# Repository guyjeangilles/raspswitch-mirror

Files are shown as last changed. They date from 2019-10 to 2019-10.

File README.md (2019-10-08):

----
# Table of Contents #
* [Introduction](#introduction)
* [Design Overview](#design-overview)
  * [Console](#console)
  * [DuinoCon](#duinocon)
* [Full Component List](#component_list)
* [Setting up the blueSMIRF as an HID Device](#setting_up_the_blueSMIRF)
* [Test The Gamepad Functionality](#test_the_gamepad)
* [Setting Up RetroPie](#setting_up_retropie)
* [Mechanical Assembly Sanity Check](#mechanical_assembly)
* [Full Assembly](#full_assembly)
  * [Console Assembly](#console_assembly)
  * [Gamepad Assembly](#gamepad_assembly)

----
**This repo is hosted on [Gitlab](https://gitlab.com/guyjeangilles/raspswitch.git). Any issues or pull requests on Github will be ignored and closed.**

# Introduction #
Welcome to the RaspSwitch repo. The steps in this readme instruct how to make
a Nintendo Switch-inspired handheld retro-gaming console. What makes this unique to other
variants is a DIY bluetooth, collapsible gamepad deemed the _DuinCon_.
 Heavy inspiration from the [SwitchBerry.](https://github.com/drew-wallace/switchberry)

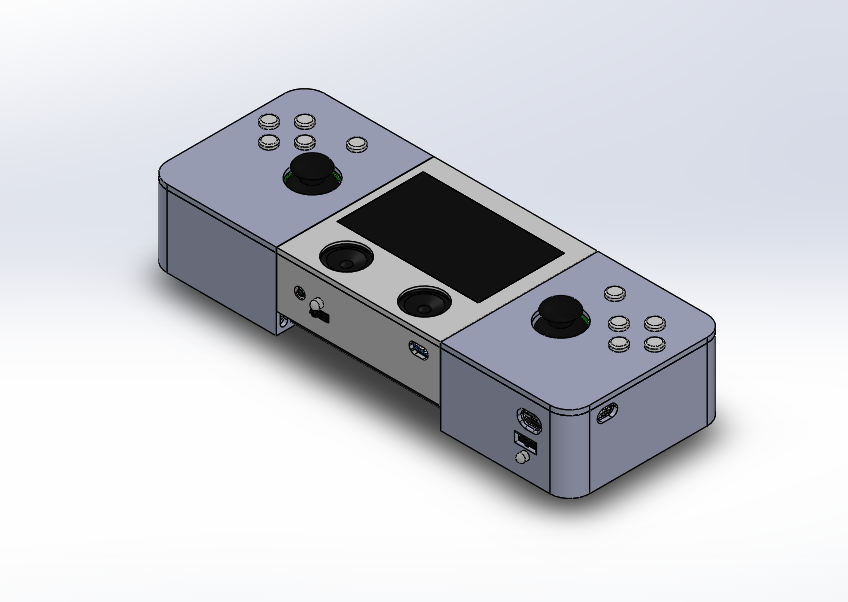
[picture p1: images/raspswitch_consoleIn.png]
RaspSwitch Console In CAD Render

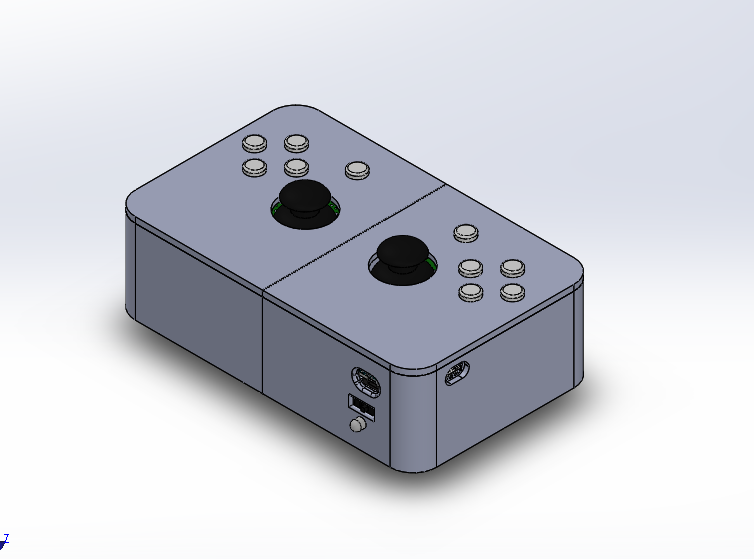
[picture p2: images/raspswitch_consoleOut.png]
RaspSwitch Console Out CAD Render


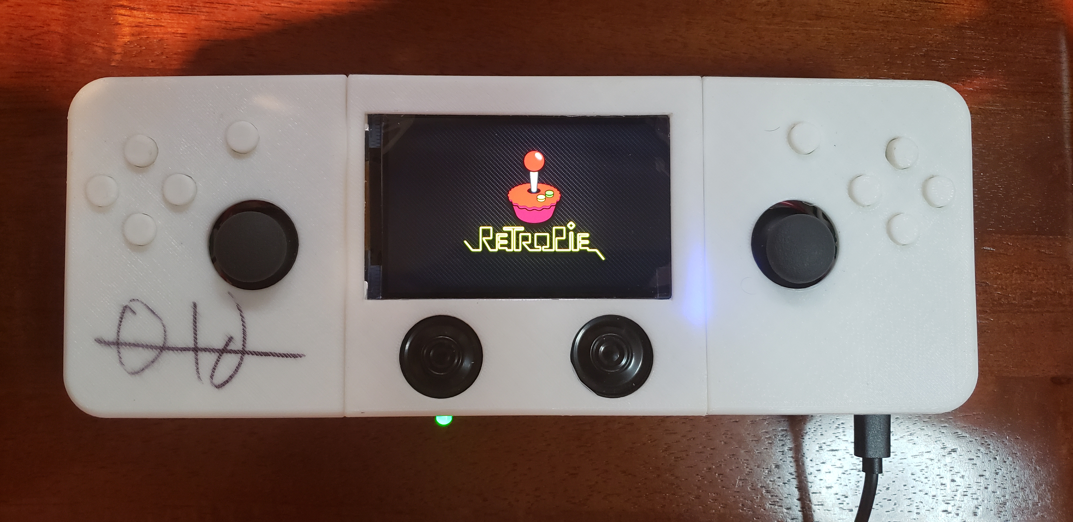
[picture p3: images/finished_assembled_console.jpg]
Finished Assembled Console

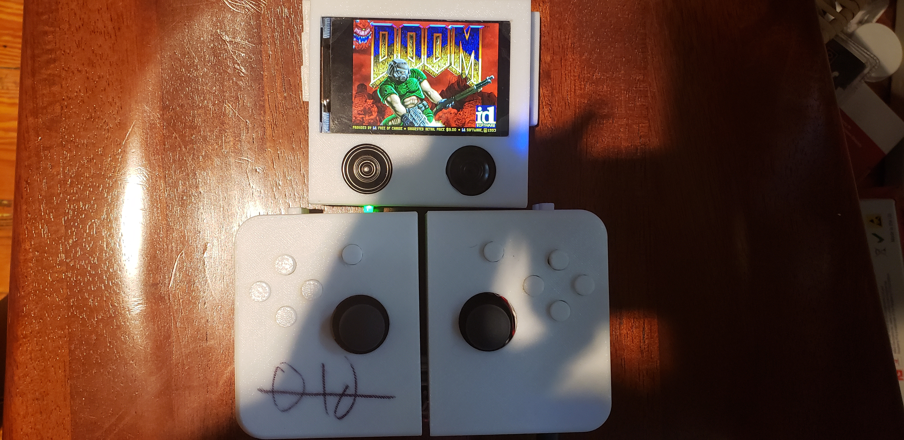
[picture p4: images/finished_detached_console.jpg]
Finished Detached Gamepad


# Design Overview #
Below are wiring diagrams of the RaspSwitch. These are for **reference only**.
Make sure you understand each component's function.

## Console ##

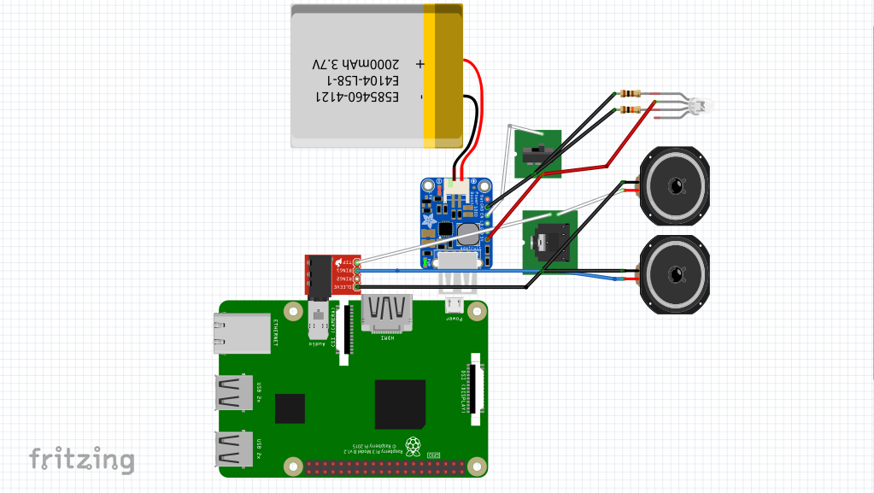
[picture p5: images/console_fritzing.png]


The console consists of a Raspberry Pi 3 A+ and the HyperPixel 4.0 as the display. A Powerboost 1000c and a 2500mAh lithium battery supply power. In practice, the battery life is ~1.5 hours. You can use an external battery pack to lengthen that. There's also circuitry to turn the console on and off with a switch, a power LED that turns on when the battery is low, and electronics that switch audio from the built-in speakers to headphones if they're plugged in.

_NOTE: I want to reiterate that the above is just for reference. Several elements are not in the fritzing diagram including the HyperPixel 4.0, USB cable from the PowerBoost 1000c, etc._

## DuinoCon ##

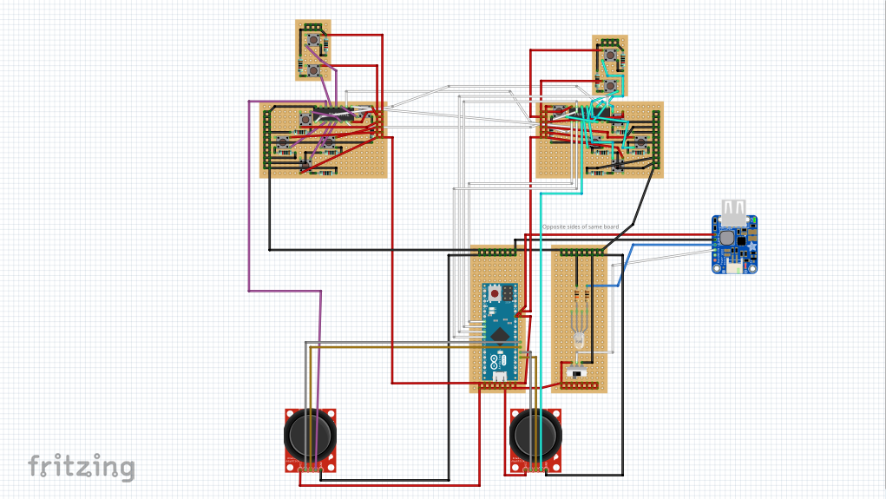
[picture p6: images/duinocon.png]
DuinoCon Fritzing Diagram


The bluetooth gamepad is fairly simple. It's main components are an Arduino Micro, two shift registers, two thumb joysticks, and a blueSMIRF module. A 1200mAh lithium ion battery and Powerboost 1000c supply power. I was getting 4+ hours of use from this battery. Mechanically speaking, the gamepad is one unit that can collapse instead of two separate gamepads like the Nintendo Switches joycons. I'll be honest, separate gamepads are probably more functional than a collapsible gamepad, but at least now you can learn from my mistakes.

# Full Component List #
- [Raspberry Pi A+ (USD 25.00 Oct2019)](https://www.adafruit.com/product/4027)
- [Arduino Micro (USD 19.80 Oct2019)](https://store.arduino.cc/usa/arduino-micro)
- [Hyperpixel 4.0 display (£36.50 Oct2019)](https://shop.pimoroni.com/products/hyperpixel-4)
- [blueSMIRF Silver (USD 27.95 Oct2019)](https://www.sparkfun.com/products/12577)
- [6" USB cable (USD 2.95 Oct 2019)](https://www.adafruit.com/product/898)
- [SN74HC165N shift register (USD 0.48 Oct2019)](https://www.digikey.com/product-detail/en/texas-instruments/SN74HC165N/296-8251-5-ND/376966)
- [M2 threaded inserts (USD 13.20)](https://www.mcmaster.com/94180a312)
- [M2x6 fasteners (USD 12.05 Oct2019)](https://www.mcmaster.com/91290a013)
- [M2x3 fasteners (USD 8.74)](https://www.mcmaster.com/91292a003)
- [M2 hex nuts (USD 4.11)](https://www.mcmaster.com/90695a025)
- [M2 washers (USD 1.06)](https://www.mcmaster.com/93475a195)
- [3" linear shaft (USD 4.56)](https://www.mcmaster.com/6061k411)
- [5" linear shaft (USD 5.07)](https://www.mcmaster.com/6061k413)
- [0.938" spring (USD 5.24)](https://www.mcmaster.com/9657k810)
- [0.5" spring (USD 7.87)](https://www.mcmaster.com/9657k268)
- [2500mAh Lithium ion battery (USD 14.95 Oct2019)](https://www.adafruit.com/product/328)
- [1200mAh Lithium ion battery (USD 9.95 Oct2019)](https://www.adafruit.com/product/258)
- [Powerboost 1000c(USD 19.95 Oct2019)](https://www.adafruit.com/product/2465)
- [Protoboards (USD 8.99 Oct2019)](https://www.amazon.com/Teenitor-Prototype-Project-Quality-Universal/dp/B01IONQQ3Y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)
- [3.5 mm audio plug (USD 2.50 Oct2019)](https://www.adafruit.com/product/2914)
- [3.5 mm audio jack (USD 0.95 Oct2019)](https://www.adafruit.com/product/1699)
- [Right angle HDMI adapter (USD 7.99 Oct2019)](https://www.amazon.com/DIZA100-4-Pack-Connectors-2-Pack-Adapters/dp/B01GFP4NQA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)
- [RGB led (USD 2.00 Oct2019)](https://www.adafruit.com/product/159)
- [SPDT switch (USD 0.95 Oct2019)](https://www.adafruit.com/product/805) _this is a little smaller than what the 3D printed parts call for but will still work_
- [Soft tactile momentary switch (USD 1.95 Oct2019)](https://www.adafruit.com/product/3101)
- [0.5W 1" speaker (USD 1.95 Oct2019)](https://www.adafruit.com/product/1890)
- [10k ohm resistors (USD 0.75 Oct2019)](https://www.adafruit.com/product/2784)
- [100 ohm resistor (USD 0.75 Oct2019)](https://www.adafruit.com/product/4293)
- [DIP IC sockets (USD 10.84 Oct2019)](https://www.amazon.com/Glarks-122Pcs-Sockets-Adaptor-Assortment/dp/B01GOLSUAU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)
- [Thumb joystick USD 3.95 Oct2019](https://www.sparkfun.com/products/9032)
- [Thumb stick breakout board (USD 1.95 Oct2019)](https://www.sparkfun.com/products/9110)
- Access to a 3D printer

# Setting up the blueSMIRF as an HID Device #
0. Load the Arduino Micro with command mode test firmware.
1. Send `$$$<cr>` via the serial monitor to enter command mode.
2. Send `SU,96` to change the baud rate to 9600 bps.
3. Send `S~,6` to switch the module to the HID profile.
4. Send `R,1` to reboot.
5. Send `SH,0220` to make the module a gamepad.
6. Send `GH` to check that it changed. The response needs to be `SA,1` or at least not `SA,0` to work.

# Test the gamepad functionality #
0. Follow the instructions in the firmware comments to wire the components on a breadboard.
Use the wiring diagrams and schematic as reference only. **DO NOT SOLDER ANYTHING YET.**
1. Connect to any bluetooth capable device and ensure the blueSMIRF is seen as a bluetooth joystick and all the buttons and analog axes work. I used [jstest-gtk](https://jstest-gtk.gitlab.io/) for debugging. There's probably a similar program for your OS.

# Setting up RetroPie #
0. Ensure you have a USB keyboard and a Ethernet connection.
1. Download RetroPie image.
2. Use [Etcher](https://www.balena.io/etcher/) (our your favorite image burning tool) to install RetroPie on a micro SD card.
3. Boot RetroPie on the Raspberry Pi.
4. Configure a USB keyboard as a RetroPie controller.
5. Update RetroPie.
6. Change the timezone to yours.
7. Change the keyboard layout to one you're familiar with.
8. Connect to wifi.
9. Enable autologin.
10. Enable SSH and change the password.
11. Register the DuinoCon as a bluetooth gamepad.
12. Configure DuinoCon as a RetroPie controller.
13. Force reconnection in background.
14. Install the HyperPixel 4.0 software with `curl https://get.pimoroni.com/hyperpixel4 | bash`
more info at https://learn.pimoroni.com/tutorial/sandyj/getting-started-with-hyperpixel-4

_NOTE: I've tried to configure the Raspberry Pi to switch between HDMI and the HyperPixel but have had modest success. You can read  up on it here and take your best shot https://forums.pimoroni.com/t/hyperpixel-selective-output-eg-on-boot/5193/3 ._

# Mechanical Assembly Sanity Check #
0. 3D print all the parts.

1. Before you install the threaded inserts,  you should assemble the 3D printed parts to make sure they mate as intended. You'll likely have to do some post-processing depending on the 3D printer you use. I modeled the parts to have excess material so they could be printed on any printer and be post-processed for proper assembly. Use the following steps as a minimum checklist for part assembly.

2. A micro SD card should be able to **slip** through slot on the side of the console. It should not stick...like at all.

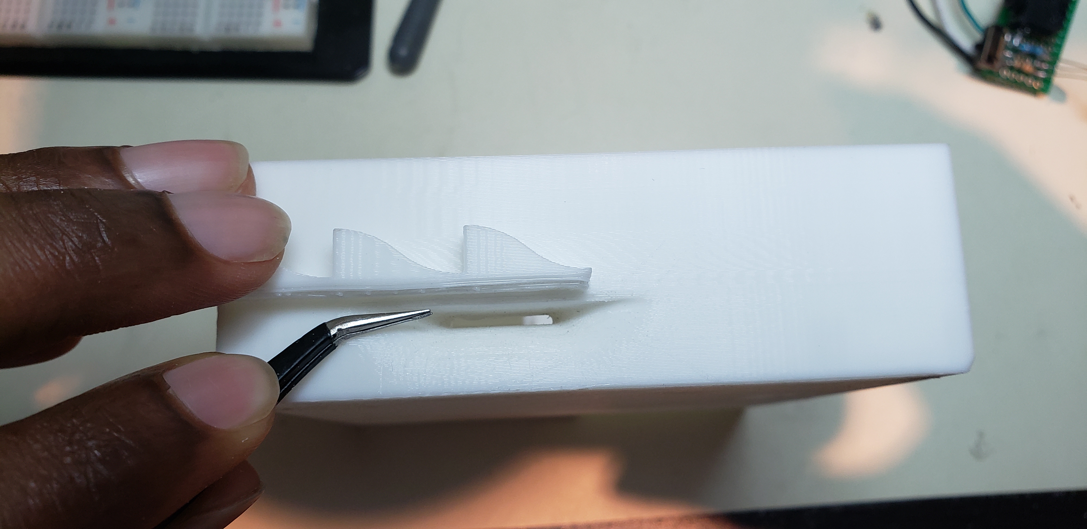
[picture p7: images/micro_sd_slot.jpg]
Micro SD Slot


3. The port for the headphone jack, SPDT switch, and RGB led  should **slip** into it's hole in the front of the console enclosure. A little sticktion is ok.

4. The console's tabs should **slip** into the gamepads slots. There should be **zero** stick...like at all.

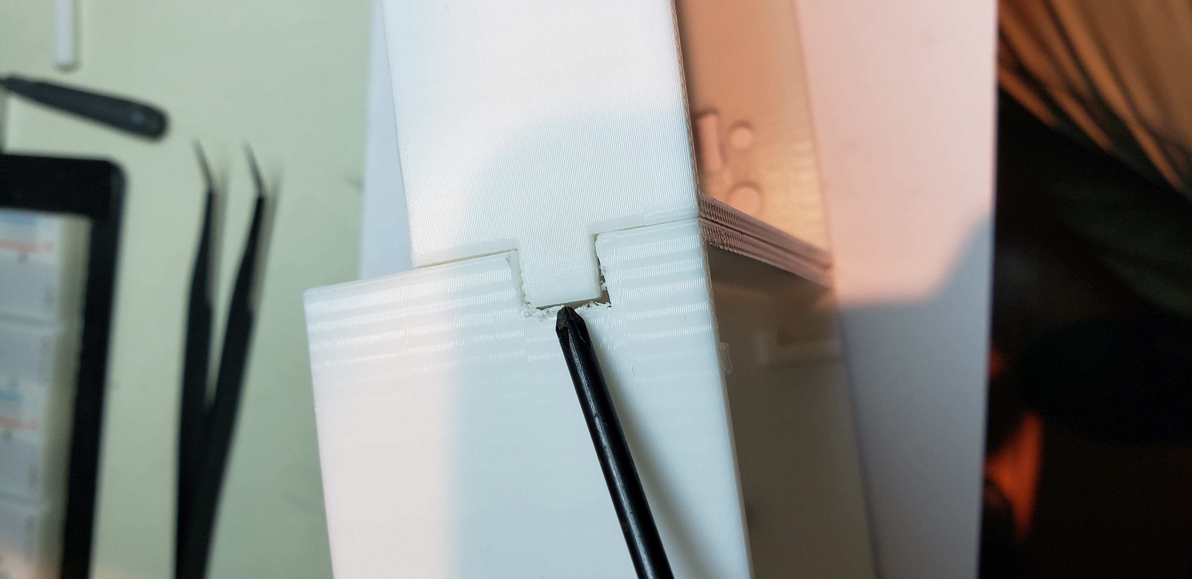
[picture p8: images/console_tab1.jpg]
Console Tabs

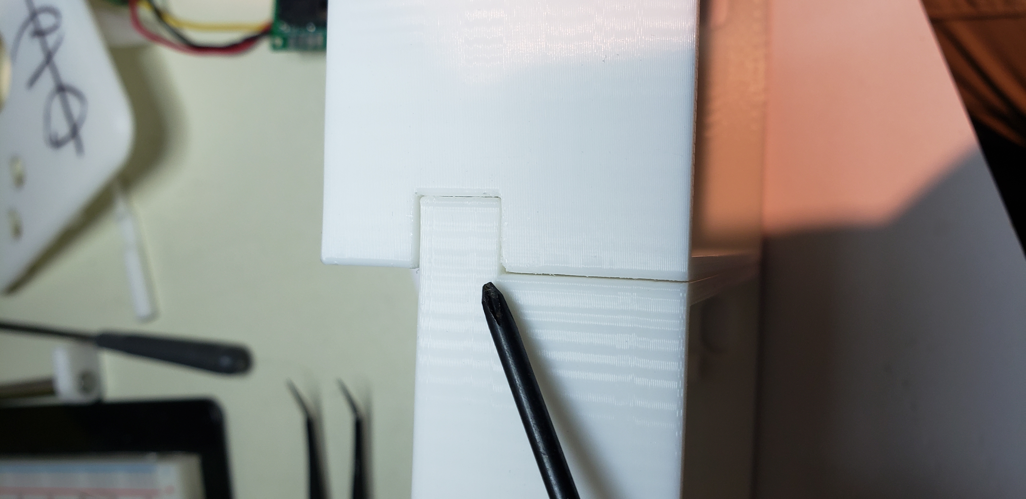
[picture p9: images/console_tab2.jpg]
Console Tabs


5. The slide bay should **slip** into the two halves of the gamepads. There should be **zero** stick...like at all.

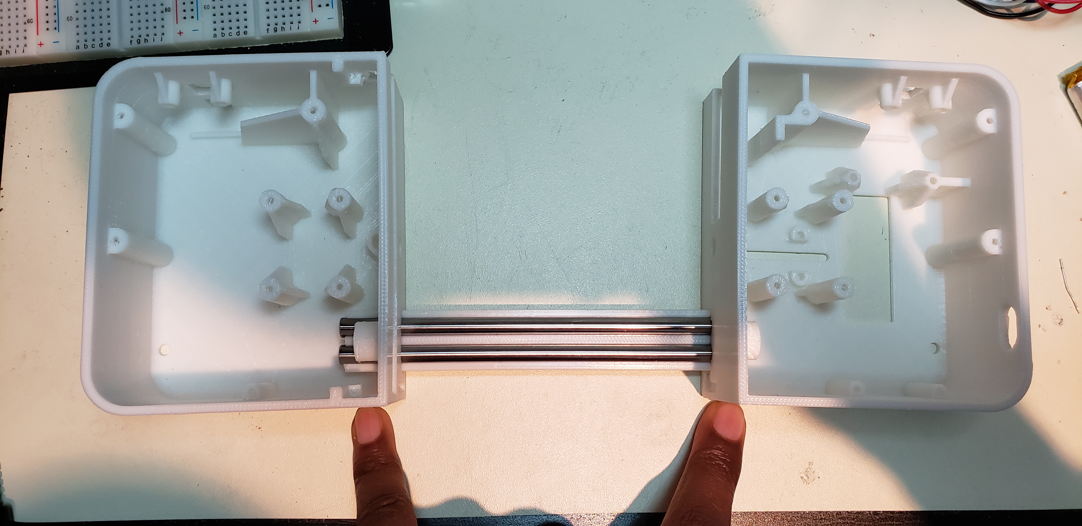
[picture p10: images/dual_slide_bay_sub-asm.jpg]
Dual Slide Bay in Gamepad Bottoms


6. The linear shaft should **slip** into the shaft guide. A little sticktion is ok.

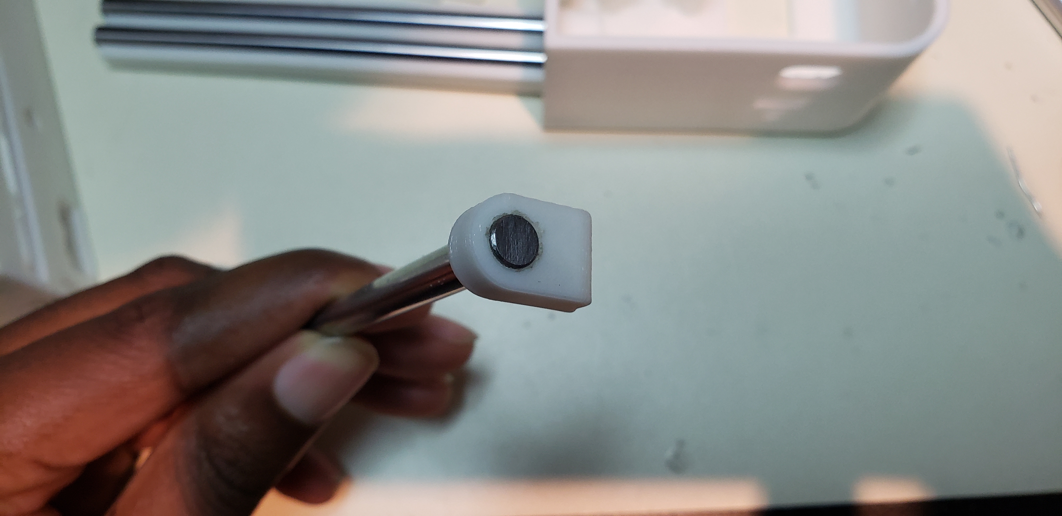
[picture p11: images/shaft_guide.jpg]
Shaft Guide


7. The console release tip should **slip** through it's housing in left gamepad half. There should be **zero** stick...like at all.

8. The console catch should **slip** though it's housing in the left gamepad half. There should be **zero** stick...like at all.

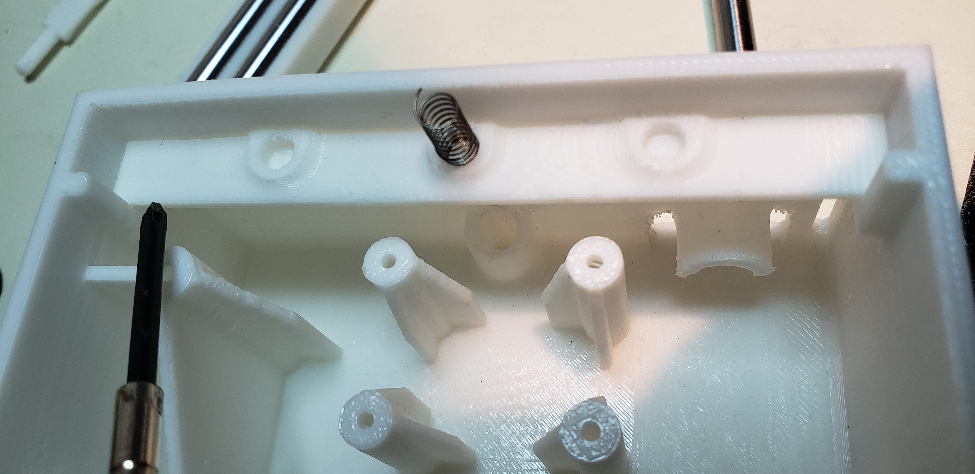
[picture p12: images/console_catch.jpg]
Console Catch


9. A spring should rest in the right gamepad catch enclosure when it's flipped upside down.

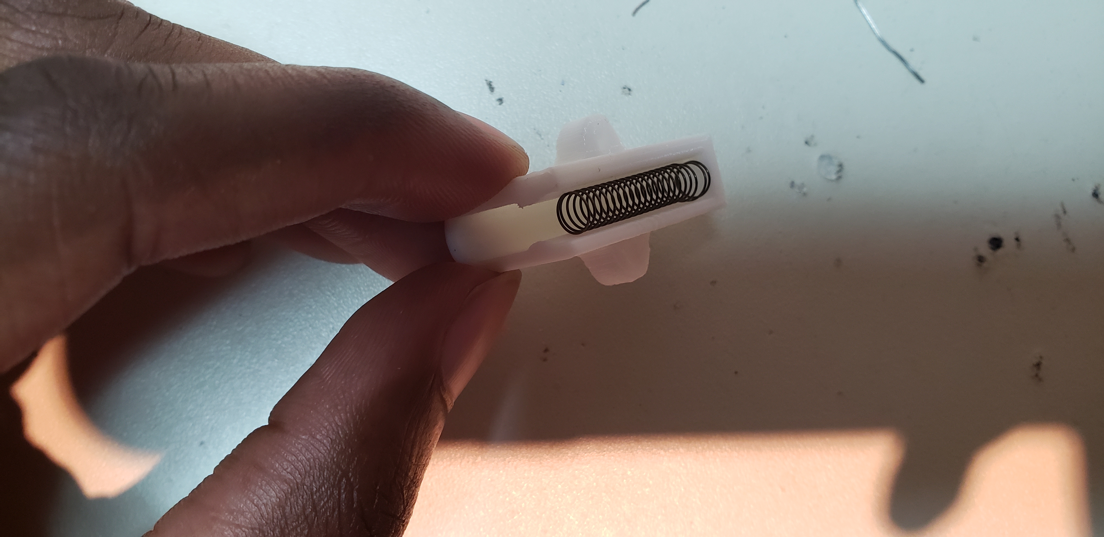
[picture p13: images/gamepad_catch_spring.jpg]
Gamepad Catch Spring


10. The assembled right gamepad catch should **slip** in and out of it's enclosure. There should be **zero** stick...like at all.

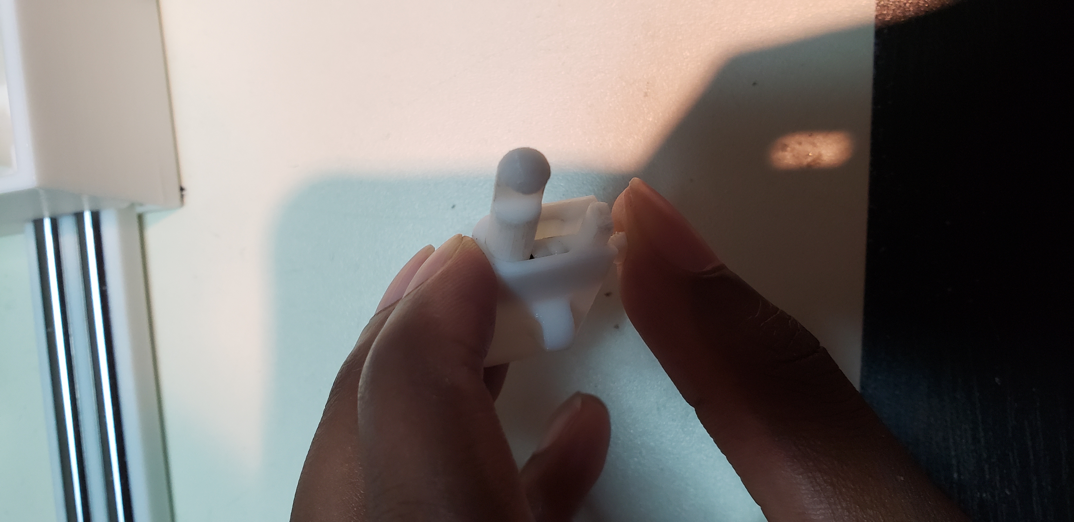
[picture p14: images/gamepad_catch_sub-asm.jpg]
Gamepad Catch Subassembly


# Full Assembly #

_NOTE:_ I'd recommend only charging one battery and leaving another in a low/near-dead state to troubleshoot the low battery fuction of the 1000C.

_ANOTHER NOTE:_ I'd recommend using stranded wire as it's more flexible than solid core.

_ONE MORE NOTE:_ You will need to cut the protoboards I link to in the full component list. I did this easily with a dremel tool.

## Console Assembly ##

### Console Component list ###

- Raspberry Pi A+ x1
- Hyperpixel 4.0 display x1
- GPIO header extension x1
- M2.5 mm shoulder x4
- M2.5 fasteners x4
- M2 threaded inserts x12
- M2x6 fasteners x10
- M2x3 fasteners x2
- 2500mAh Lithium ion battery x1
- Powerboost 1000c x1
- Appropriately sized protoboard for audio/power circuit x1
- 3.5 mm audio jack x1
- 3.5 mm audio plug x1
- Right angle HDMI adapter x1
- RGB led x1
- SPDT switch x1
- 0.5W 1" speaker x2
- 10k ohm resistor x1
- 10 ohm resistor x1
- all 3D printed parts

0. Test your components on a breadboard

1. Seriously, save yourself some time and connect everything, raspberry pi, Arduino, all the components on a breadboard and use the joysticks, buttons, headphone jacks, switches...test all of this before you start soldering anything.

2. Make sure you did the mechanical assembly right.

3. I'm being repetitive but seriously if you skipped the mechanical assembly part above go back up and do it.

4. Solder the audio/power PCB including the Powerboost 1000c, 3.5mm plug, and speakers that I forgot to solder in the photo below.

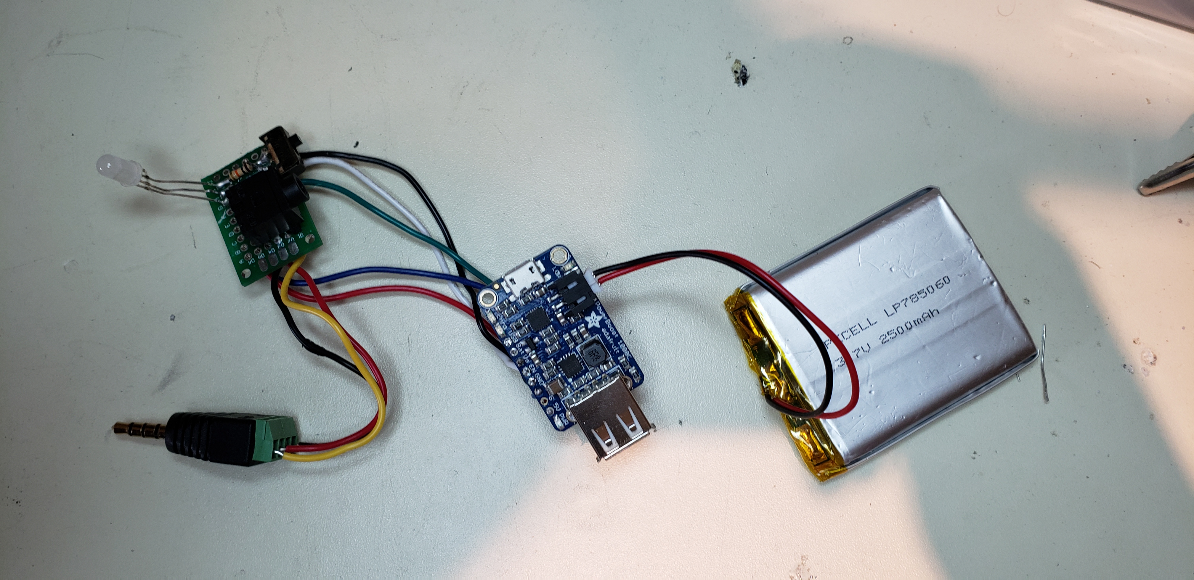
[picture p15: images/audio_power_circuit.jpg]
Audio/Power Circuit


5. Test that the audio jack and speakers work in a known good audio source. Also, check that the LED turns green and red as expected and the slide switch works.

6. Install the threaded inserts in the top and bottom half of the console enclosures.

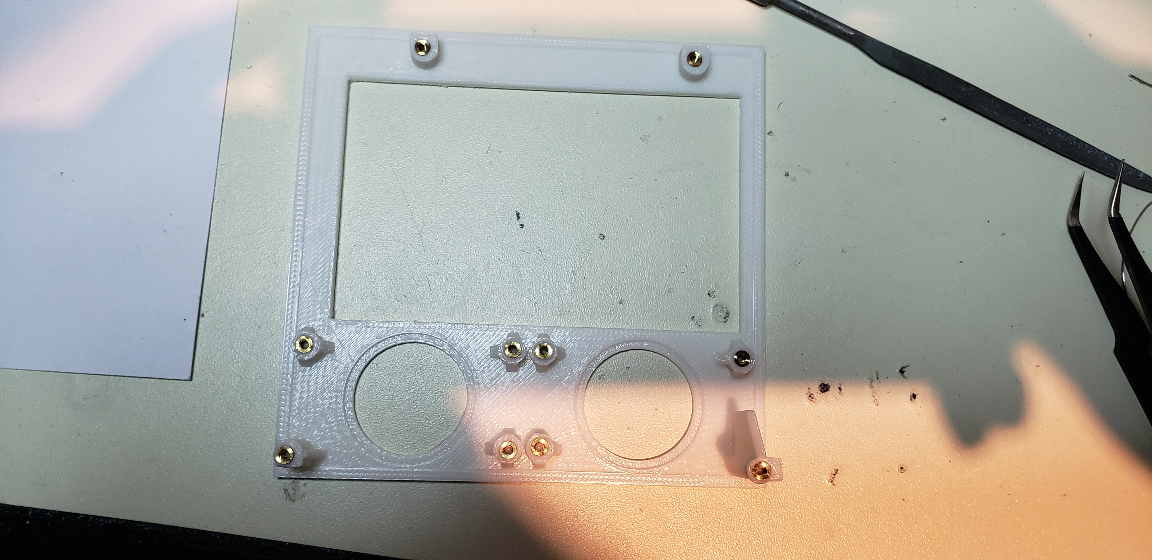
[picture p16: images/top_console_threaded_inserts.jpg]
Top Console Threaded Inserts


7. Install the audio/power PCB, don't install the Powerboost 1000c yet. The M2X3 fastener works best here.

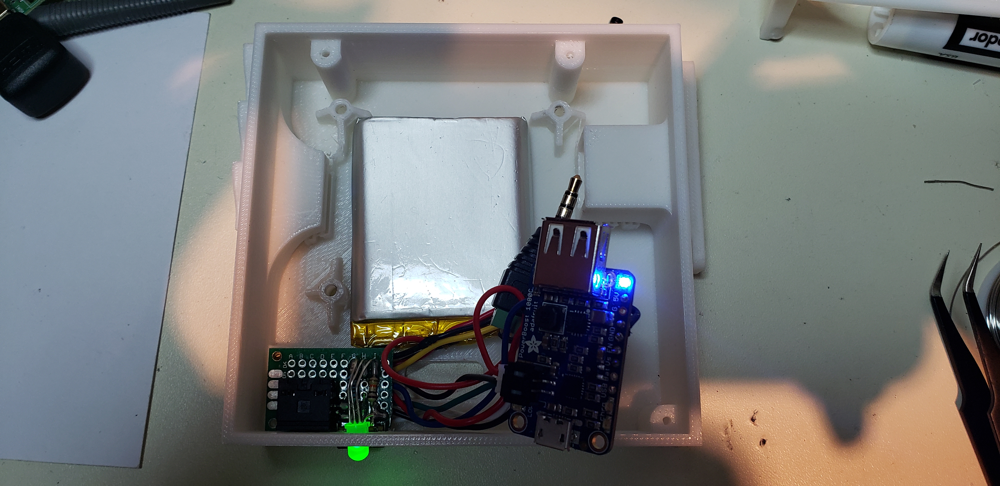
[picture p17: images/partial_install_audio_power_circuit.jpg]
Partial Install of Audio/Power Circuit


8. Install the HDMI adapter and3.5mm plug onto the Pi. Then install the Pi into the bottom half of the console enclosure **without** the micro SD card.  It's easiest to slide the Pi in sideways.

9. Install the Powerboost 1000c, but don't fasten down the fastener too tight as you might need to adjust it for the next step. The M2x3 fastener works best here.

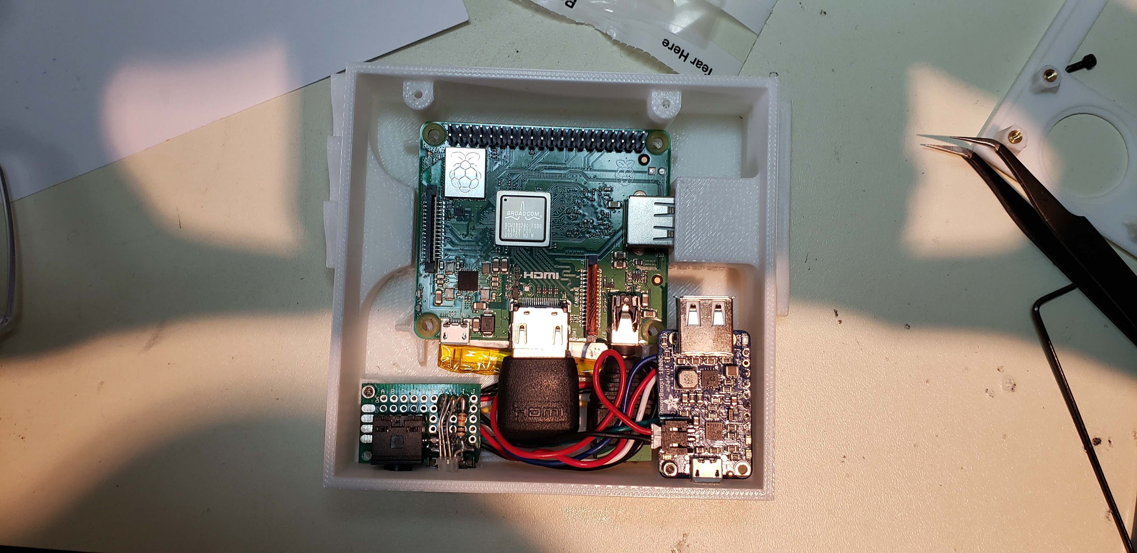
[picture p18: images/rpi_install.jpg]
Raspberry Pi Installed


10. Attach a USB cable to the Powerboost 1000c and Raspberry Pi. You might need to push down the LED wires to accomplish this.

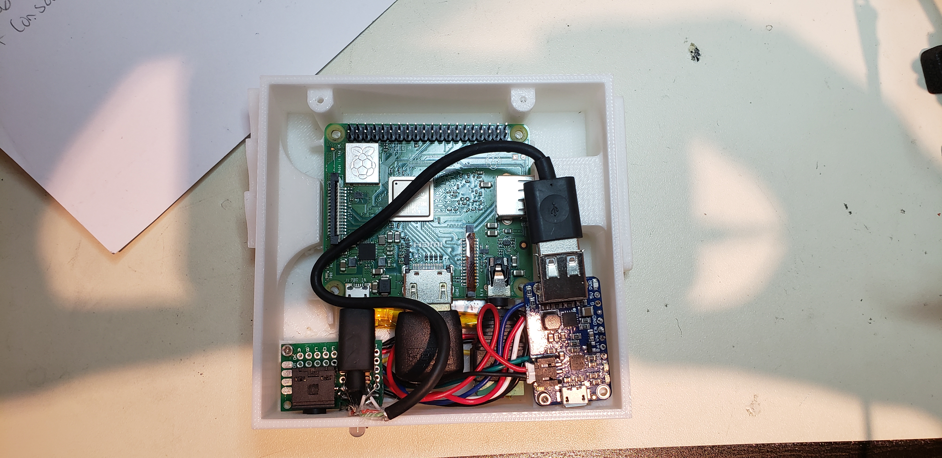
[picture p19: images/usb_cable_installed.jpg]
USB Cable Installed


11. Install the threaded inserts and header pin extender onto the Hyperpixel 4.0. Then install the Hyperpixel 4.0 onto the Raspberry Pi. Once the screen is on, screw in the fasteners included with the display (M2.5) from the bottom half of the console into the raspberry pi.

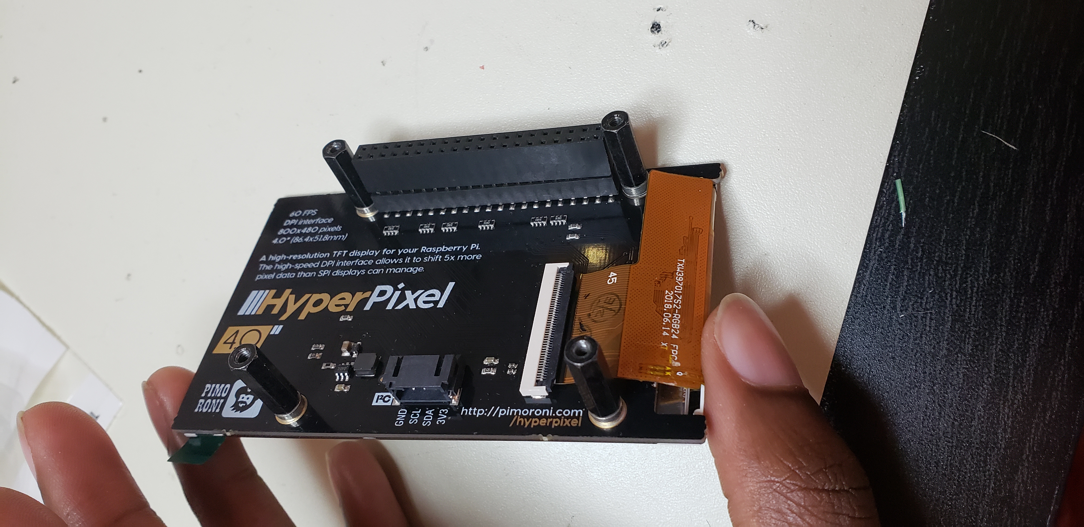
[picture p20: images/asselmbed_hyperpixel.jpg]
Assembled HyperPixel


12. Install the speakers into the top half of the console. M2x6 fasteners works best here.

13. Install the top half of the console enclosure onto the bottom half of the enclosure. Use M2x6 fasteners.

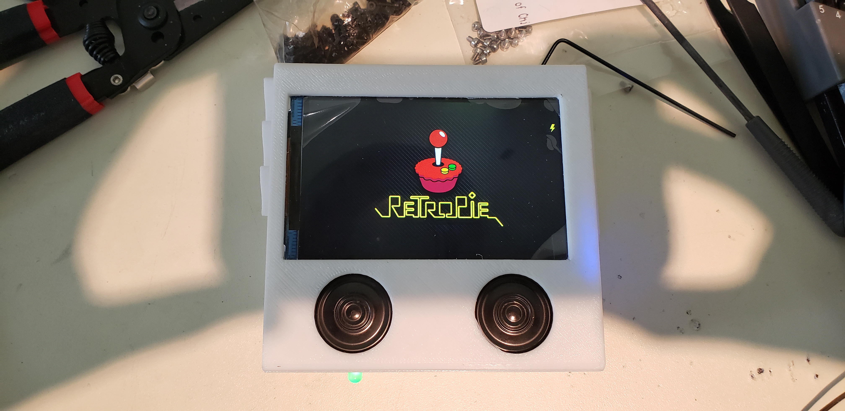
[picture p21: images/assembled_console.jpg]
Assembled Console


## Gamepad Assembly ##

_NOTE:_ This is a complex soldering assembly. No less than 7 boards need to be soldered to the Arduino in some way. It's worth your time and sanity to review the circuit to make sure you understand what each wire is for. You may also want to practice making solder bridges.

### Component List ###

- Arduino Micro x1
- 20 pin DIP IC socket x1
- Powerboost 1000c
- M2 threaded inserts x17
- M2x6 fasteners x17
- M2 hex nuts x4
- M2 washers x4
- blueSMIRF
- 1200mAh lithium ion battery
- Joystick x2
- Joystick breakout board x2
- appropriately sized protoboard for the right gamepad face buttons x1
- appropriately sized protoboard for the left gamepad face buttons x1
- appropriately sized protoboard for the shoulder buttons x2
- 3cmx7cm protoboard x1
- Soft tactile momentary swtich x14
- 10k ohm resistor x15
- 100 ohm resistor x1
- SN74HC165N PISO shift register x2
- 16 pin DIP IC socket x2
- 3" linear saft x2
- 5" linear shaft x2
- 0.938" spring 1
- 0.5" spring x 3
- all 3D printed parts

0. Did you test the components on a breadboard? Because if you didn't your going to have a bad time.

1. Assemble all your components and place them on their respective boards.

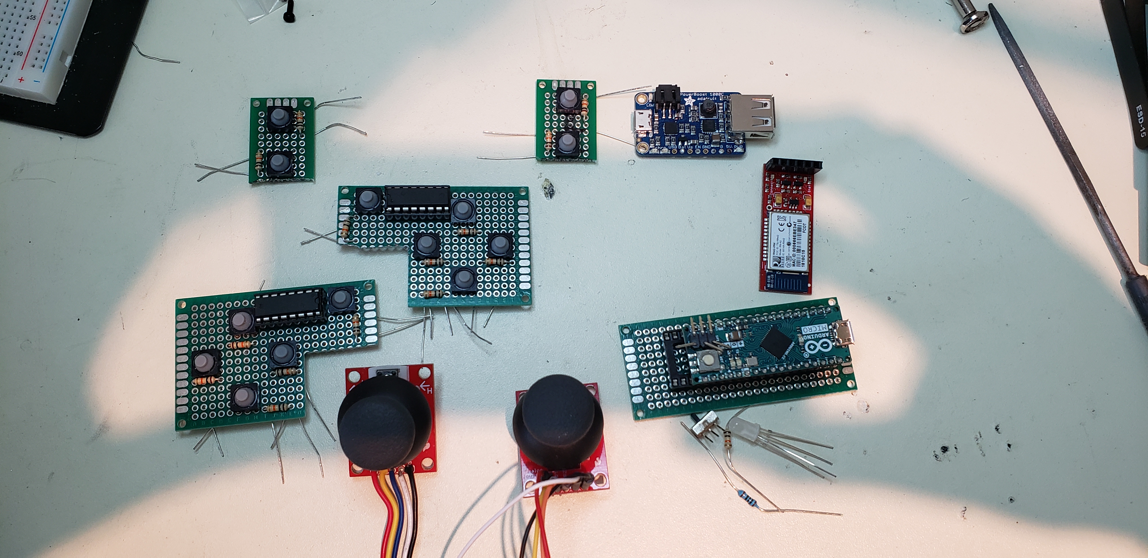
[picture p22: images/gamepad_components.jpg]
Electronic Components


_NOTE:_ To ease debugging, these steps will instruct to only solder the components for the right half of the gamepad then test the circuit.

_ANOTHER NOTE:_ Depending on the gauge wire/DIP IC socket leads/protoboard you're using, the hookup wire AND the DIP IC lead  could fit in one through hole. It will make soldering a lot neater if you consolidate.

_ONE LAST NOTE:_ You'll need to bend the leads of the ISP on the Arduino Micro as shown in the picture above.

2. Solder *ONLY* the 5V and GND pins of the Arduino Micro to the protoboard. Make sure it's in a location that aligns with the USB access port in the bottom half of the right gamepad enclosure. Solder the 5V and GND pins of the Powerboost 1000c to the 5V and GND pins of the Arduino Micro. Check your soldering by powering on the Arduino Micro.

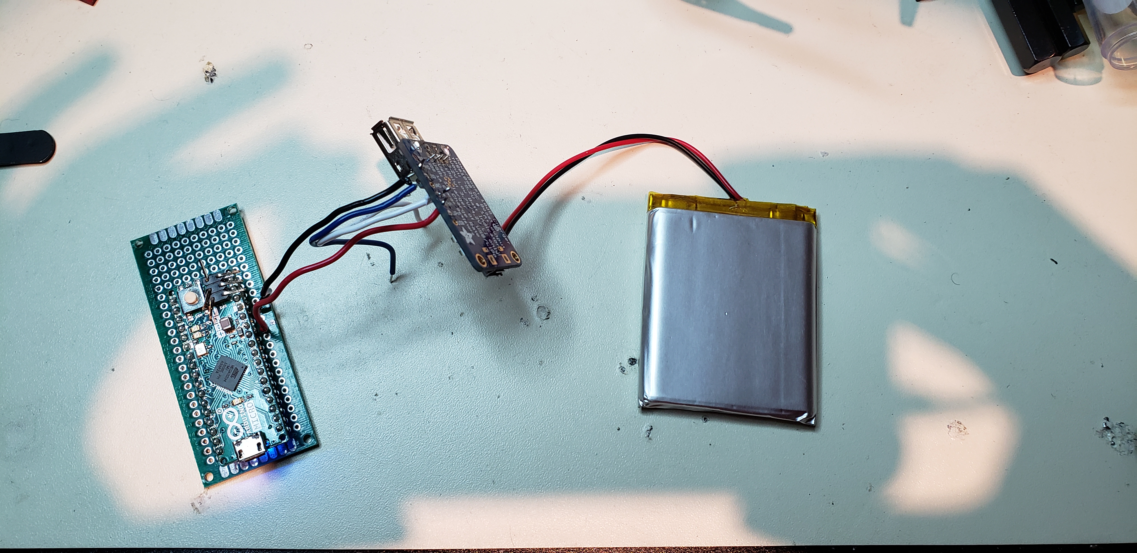
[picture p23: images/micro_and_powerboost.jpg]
Micro with Powerbooxt 1000c


_NOTE:_ The VS pin should be soldered directly to the SPDT Switch, but everything else that requires 5V, (Arduino, buttons, etc.), should be connected to the 5V pin of the Powerboost.

3. Solder the SPDT switch, RGB led, and accompanying resistors to the protoboard. I used the solder pads as power and ground planes, but you can solder your own way if you like. Check your soldering by turning the Arduino Micro on and off with the switch.

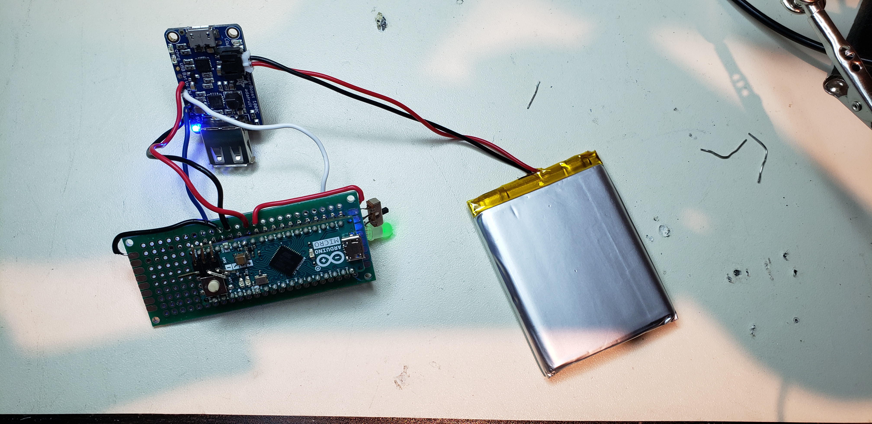
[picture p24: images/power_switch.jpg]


4. Solder all of the components for the right half of the gamepad, connect the electronics to a bluetooth compatible device and check that everything works. Don't solder any of the components for the left half of the gamepad yet.

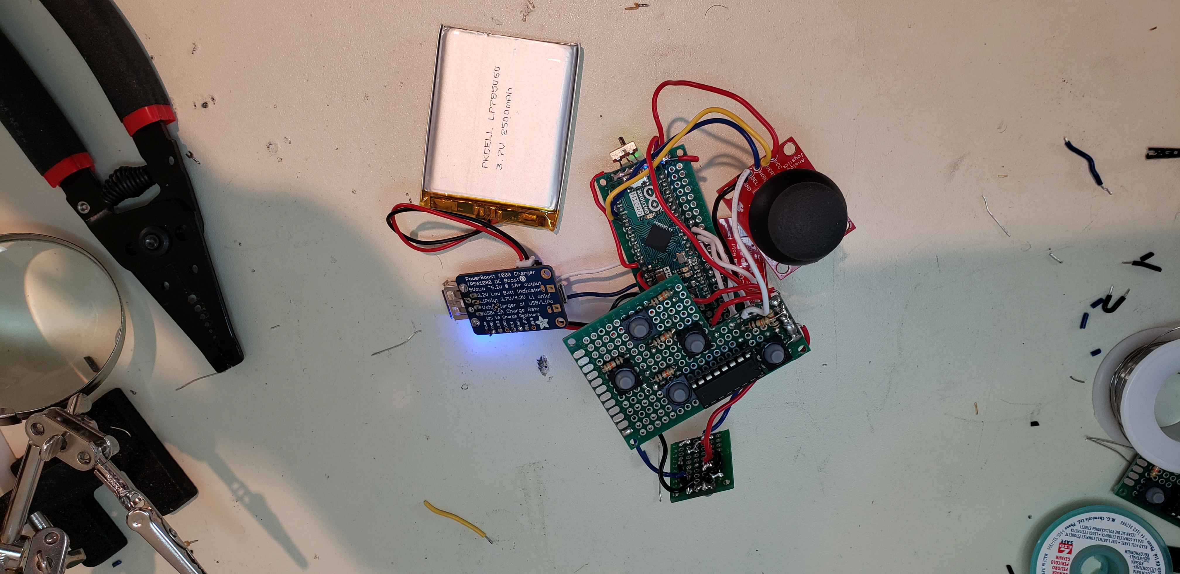
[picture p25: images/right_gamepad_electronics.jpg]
Right Gamepad Electronics


5. Install the M2 threaded inserts into the shaft guides.

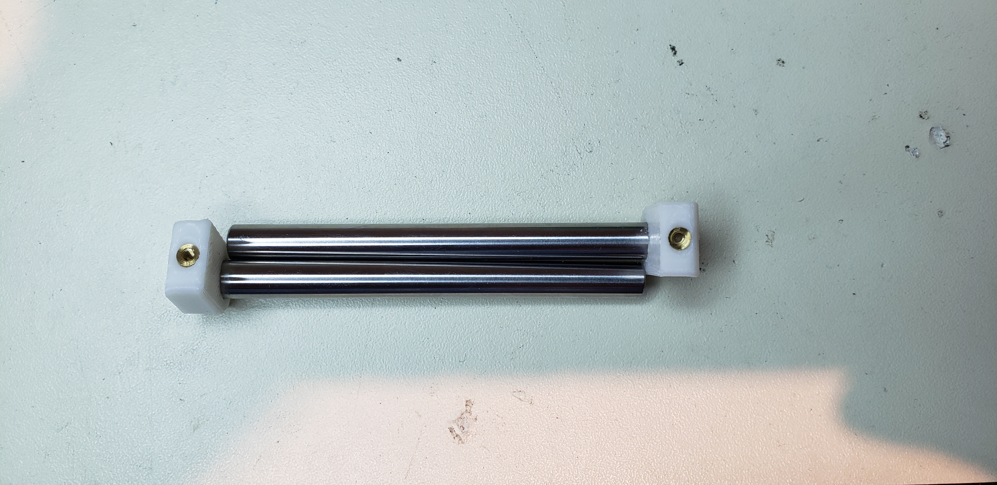
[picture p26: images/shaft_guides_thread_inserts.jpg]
Shaft Guides with Thread Inserts


6. Install the 5" linear shafts in the dual shaft bay and install the M2 threaded inserts into the dual shaft bay.

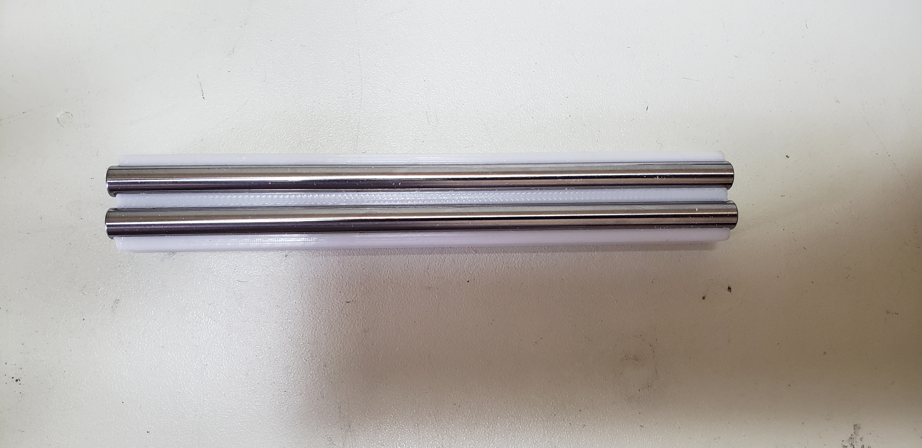
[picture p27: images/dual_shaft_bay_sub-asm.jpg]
Shafts in Shaft Bay

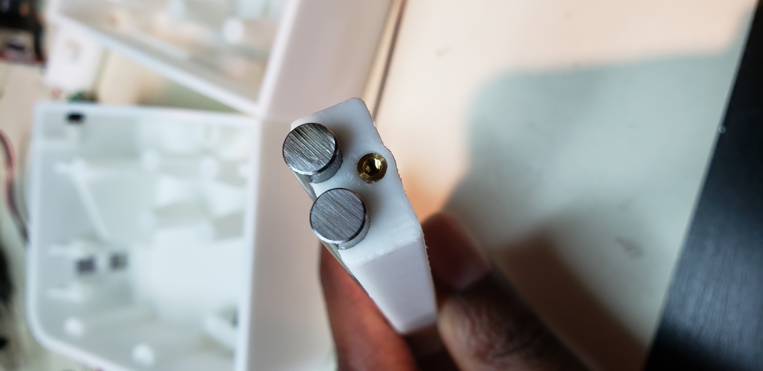
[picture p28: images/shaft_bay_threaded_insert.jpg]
Shaft Bay with Thread Insert


7. Insert the 3" linear shafts into the shaft guide. Hold the shaft guide/linear shaft sub-assembly into place in the bottom gamepad halves and slide the dual shaft bay subassembly into place.

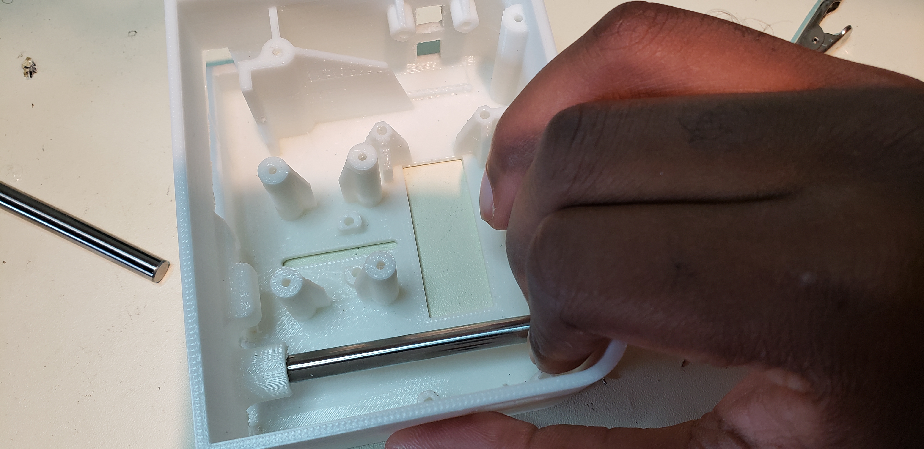
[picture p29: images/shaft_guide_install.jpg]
Install the Shaft Guide


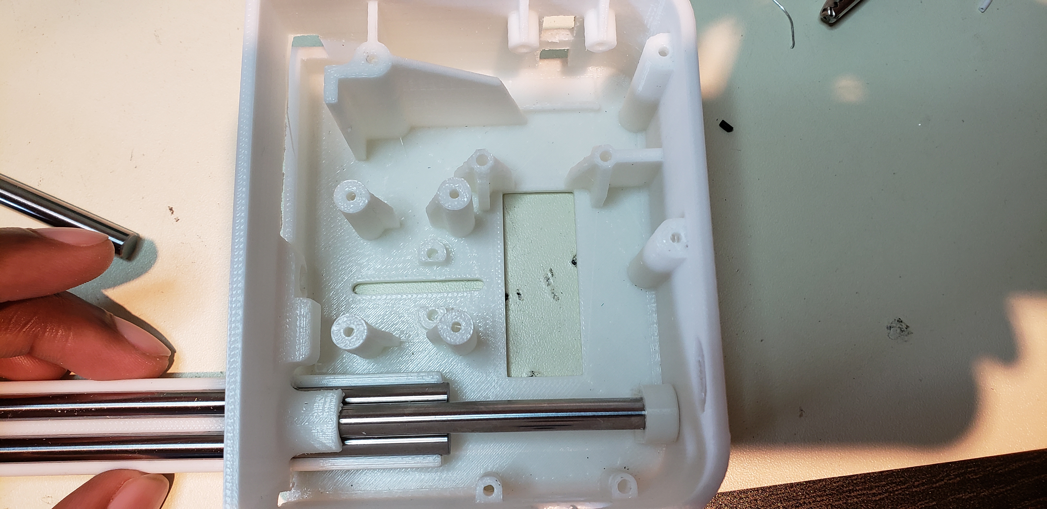
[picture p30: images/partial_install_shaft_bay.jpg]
Shaft Bay Partially Installed


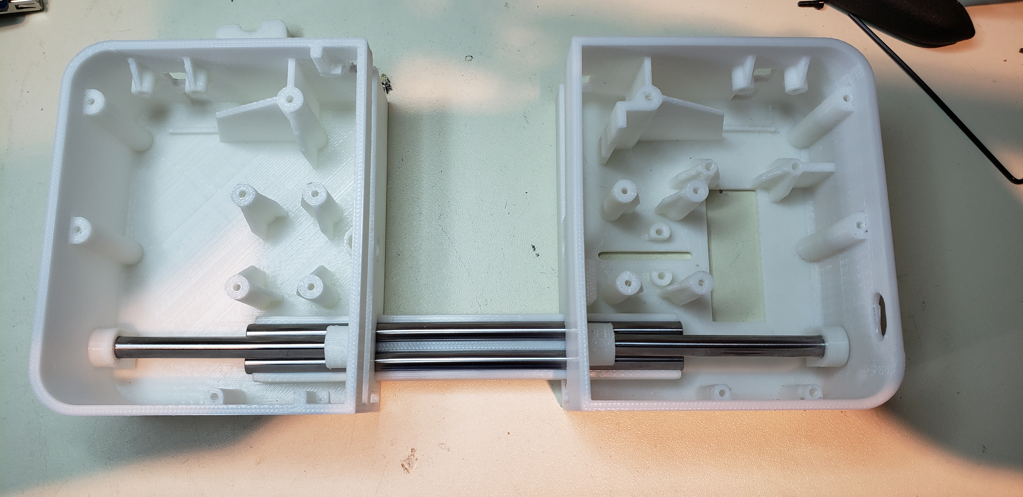
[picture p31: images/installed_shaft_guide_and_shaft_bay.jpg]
Shaft Bay Installed


8. Fasten the end caps into place. Fasten the shaft guide into place.

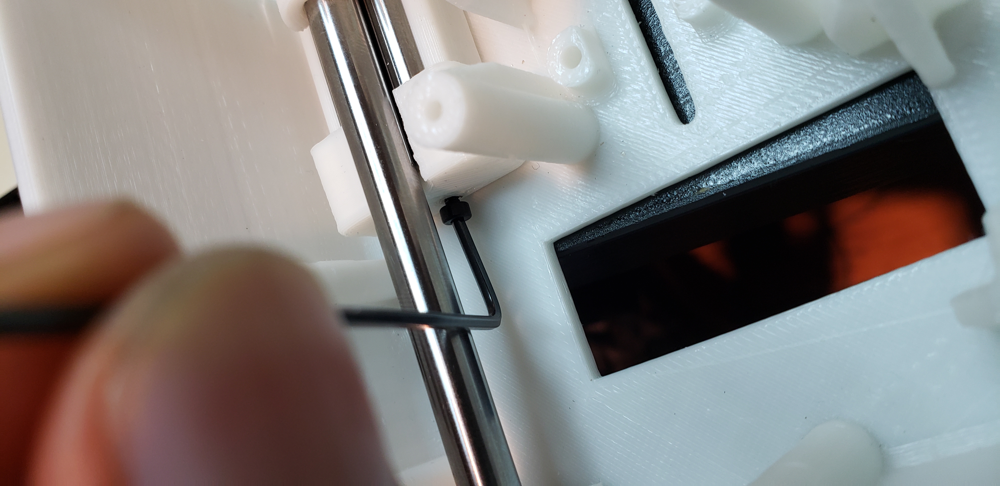
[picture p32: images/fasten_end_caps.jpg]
Fasten End Caps


9. Now we're going to switch back to electronics. Solder the second SN74HC165N PISO shift register, push buttons and accompanying resistors onto their PCBs. Solder VCC, GND, and SEL pins of the left joystick to this PCB assembly. *DO NOT* solder the HOR or VER pins yet.

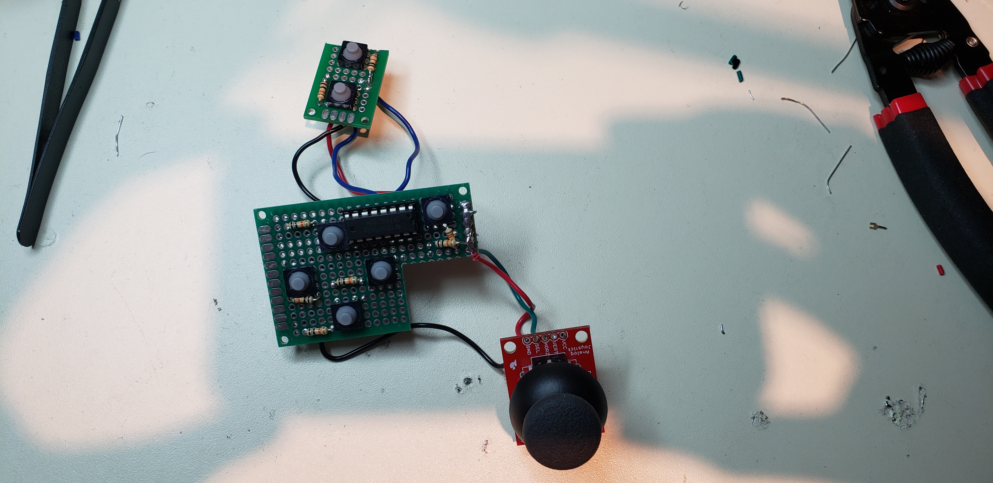
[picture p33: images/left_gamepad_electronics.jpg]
Left Gamepad Electronics


10. Cut *long* (9"+ at the very least) pieces of hook up wire. You need 2 wires for 5V and GND, 2 wires for HOR and VER of the joystick, 4 wires for the SN74HC165N PISO shift register. Solder the remaining connections. Before you fasten any boards, connect the Arduino to a bluetooth capable device and make sure everything is working properly.

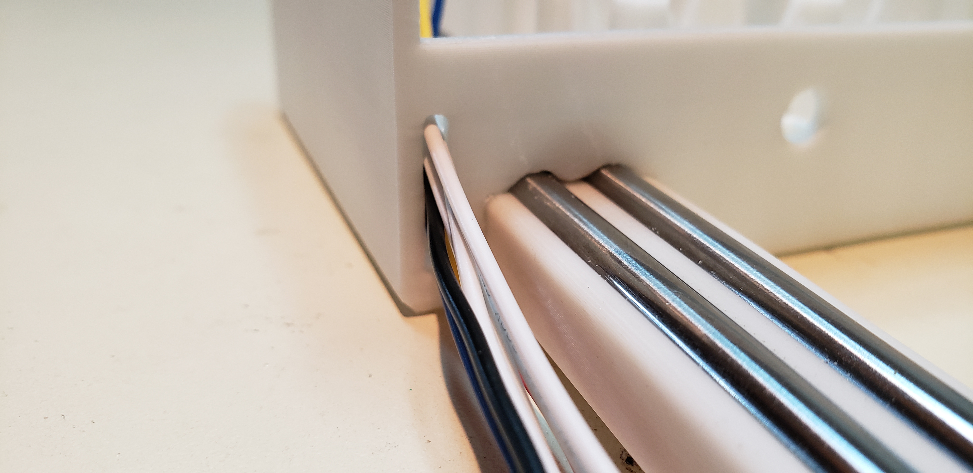
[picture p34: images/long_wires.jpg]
Inter-gamepad Wires

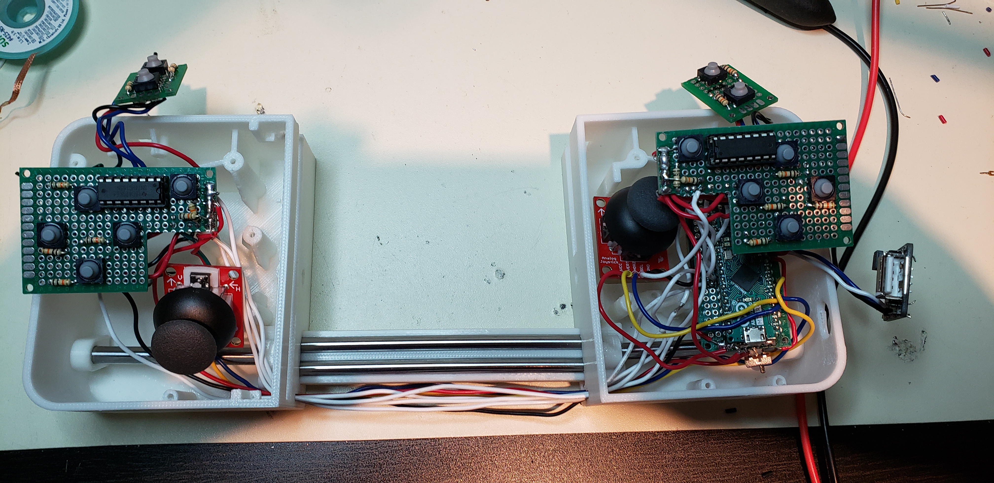
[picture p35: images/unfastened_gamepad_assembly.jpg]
Unfastened Gamepad Electronics


11. We're switching back to the 3D printed parts. Install M2 threaded inserts into the top and bottom half of the gamepad enclosures.

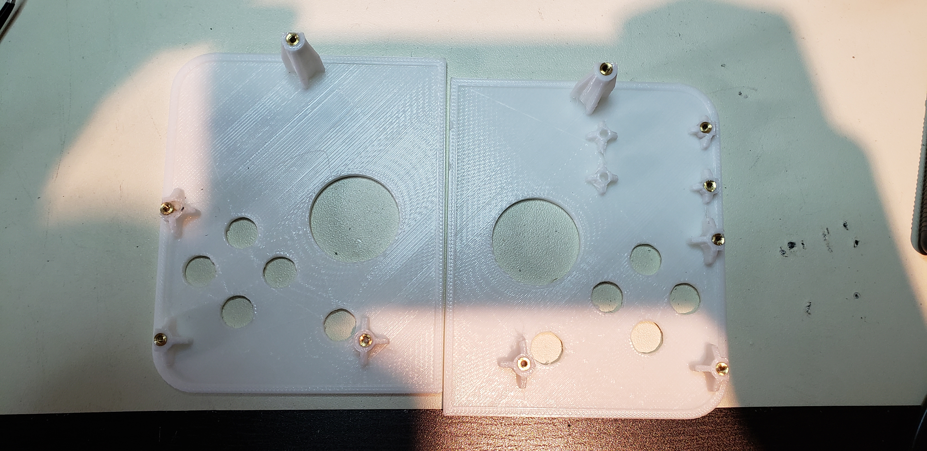
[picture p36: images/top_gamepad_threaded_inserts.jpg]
Gamepad Top Thread Inserts

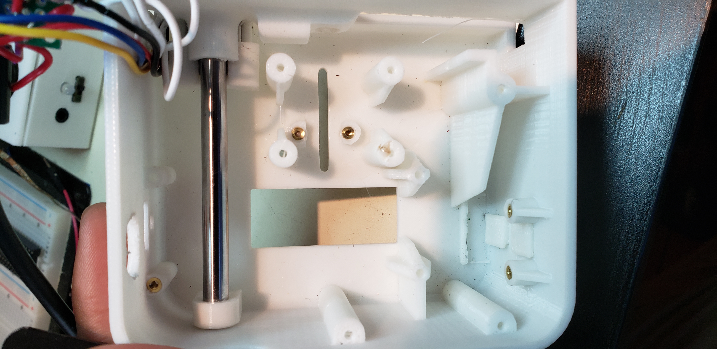
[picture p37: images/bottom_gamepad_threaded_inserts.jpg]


12. Install M2 threaded inserts into the right gamepad release slide and fasten it to the right gamepad catch.

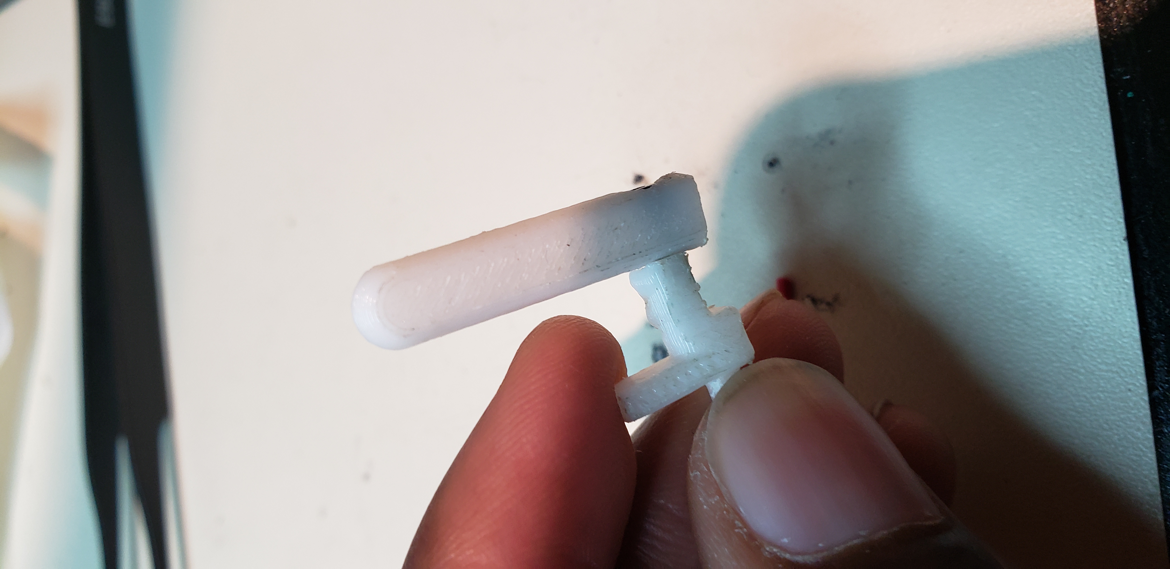
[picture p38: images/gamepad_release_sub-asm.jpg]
Gamepad Release Slide


13. Put the right gamepad catch and release assembly into place. Place the 0.938" spring into place. Fasten the enclosure.

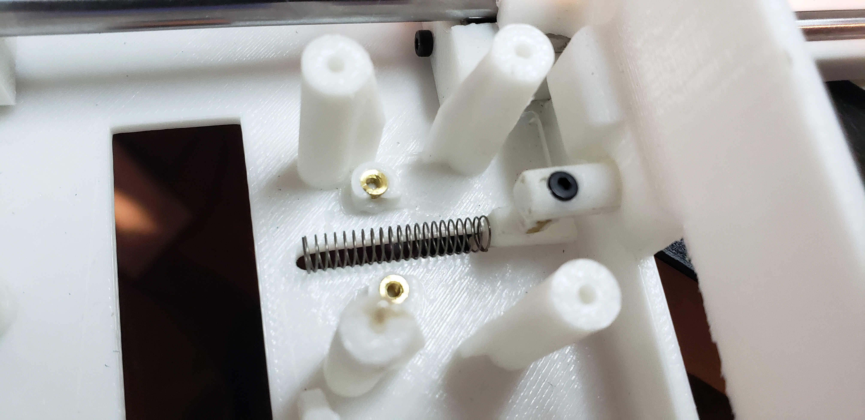
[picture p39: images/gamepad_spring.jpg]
Gamepad Spring

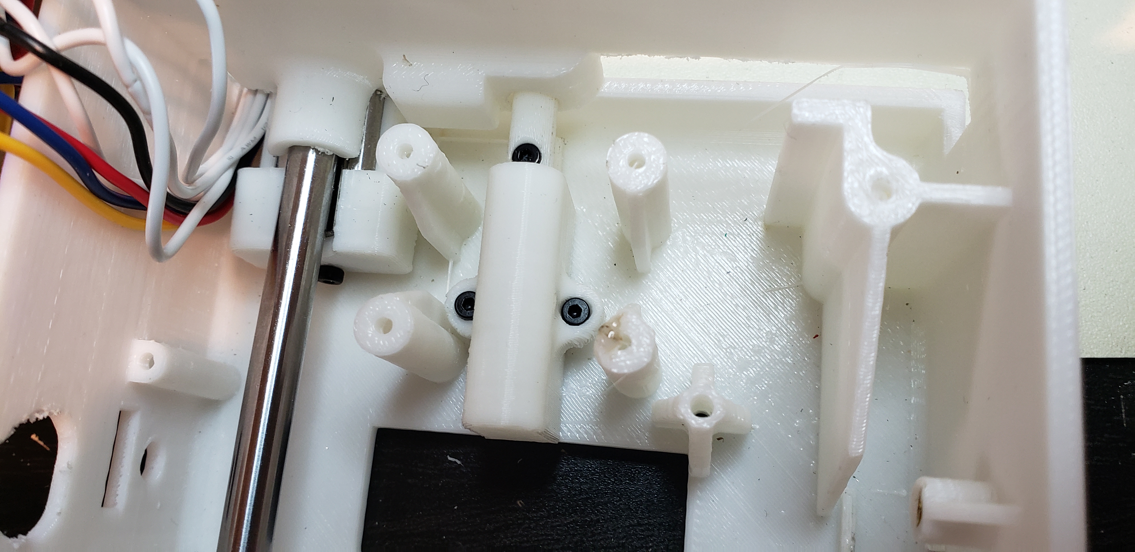
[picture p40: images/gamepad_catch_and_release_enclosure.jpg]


14. Press fit the blueSMIRF into place.

blurSMIRF

15. Install the shoulder button PCB. M2x3 fasteners work best here. I found it easier to fasten this PCB with the DuinoCon on it's side.

Sidways DuinoCon
Installed Shoulder PCB

16. Put Arduino Micro PCB into place and fasten it with a M2x3.

Installed Arduino Micro

17. Place the joystick PCB into place and fasten it with a M2 hex nut and a washer in between the nut and joystick board.

Thumbstick Install

18. Fasten the face button PCB into place and put the 3D printed buttons on the momentary switches. Put the top right half on top and fasten it into place.

Finished Right Gamepad

19. The left gamepad assembly follows a similar procedure except for a key difference: the console catch and release. After installing the left thumb joystick, install the gamepad release tip.

Installed Release Tip

20. Install three 0.5" springs into the console catch, then install the console catch into the left gamepad.

Installed Console Catch

21. Install the rest of the PCBs and buttons as before and fasten the top into place. You're done!

Finished Gamepad

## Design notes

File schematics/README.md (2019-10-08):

These schematics were made with KiCad and can be opened as an hierarchal schematic. The central schematic being *DuinoCon.sch*.

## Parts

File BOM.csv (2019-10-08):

Item | Units per Assembly | Unit Cost | Units per Package | Package Cost | Cost Per Assembly | URL
Raspberry Pi 3 A+ | 1 | $25.00 | 1 | $25.00 | $25.00 | https://www.adafruit.com/product/4027
Arduino Micro | 1 | $19.80 | 1 | $19.80 | $19.80 | https://store.arduino.cc/usa/arduino-micro
Hyperpixel 4.0 | 1 | $36.50 | 1 | $36.50 | $36.50 | https://shop.pimoroni.com/products/hyperpixel-4
blueSMIRF Silver | 1 | $27.95 | 1 | $27.95 | $27.95 | https://www.sparkfun.com/products/12577)
6” USB micro Cable | 1 | $2.95 | 1 | $2.95 | $2.95
SN74HC165N | 2 | $0.48 | 1 | $0.48 | $0.96 | https://www.digikey.com/product-detail/en/texas-instruments/SN74HC165N/296-8251-5-ND/376966
M2x6 fasteners | 27 | $0.12 | 100 | $12.05 | $3.25 | https://www.mcmaster.com/94180a312
M2x3 fasteners | 2 | $0.17 | 50 | $8.74 | $0.35 | https://www.mcmaster.com/91292a003
M2 Hex Nut | 4 | $0.04 | 100 | $4.11 | $0.16 | https://www.mcmaster.com/90695a025
M2 washers | 4 | $0.01 | 100 | $1.06 | $0.04 | https://www.mcmaster.com/93475a195
3” linear shaft | 2 | $4.56 | 1 | $4.56 | $9.12 | https://www.mcmaster.com/6061k411
5” linear shaft | 2 | $5.07 | 1 | $5.07 | $10.14 | https://www.mcmaster.com/6061k413
0.938” spring | 1 | $0.44 | 12 | $5.24 | $0.44 | https://www.mcmaster.com/9657k810
0.5” spring | 3 | $0.66 | 12 | $7.87 | $1.97 | https://www.mcmaster.com/9657k268
2500 mAh Lithium ion battery | 1 | $14.95 | 1 | $14.95 | $14.95 | https://www.adafruit.com/product/328
1200mAh Lithium ion battery | 1 | $9.95 | 1 | $9.95 | $9.95 | https://www.adafruit.com/product/258
Powerboost 1000c | 2 | $19.95 | 1 | $19.95 | $39.90 | https://www.adafruit.com/product/2465
Protoboards | 6 | $0.30 | 30 | $8.99 | $1.80 | https://www.amazon.com/Teenitor-Prototype-Project-Quality-Universal/dp/B01IONQQ3Y
3.5mm audio plug | 1 | $2.50 | 1 | $2.50 | $2.50 | https://www.adafruit.com/product/2914)
3.5mm headphone jack | 1 | $0.95 | 1 | $0.95 | $0.95 | https://www.adafruit.com/product/1699
Right angle HDMI adapter | 1 | $2.00 | 4 | $7.99 | $2.00 | https://www.amazon.com/DIZA100-4-Pack-Connectors-2-Pack-Adapters/dp/B01GFP4NQA
RGB LED | 1 | $2.00 | 1 | $2.00 | $2.00 | https://www.adafruit.com/product/159
SPDT switch | 1 | $0.95 | 1 | $0.95 | $0.95 | https://www.adafruit.com/product/805
Soft Tactile Momentary Switch | 14 | $0.20 | 10 | $1.95 | $2.73 | https://www.adafruit.com/product/3101
0.5W 1” Speaker | 2 | $1.95 | 1 | $1.95 | $3.90 | https://www.adafruit.com/product/1890
10k ohm resistor | 16 | $0.03 | 25 | $0.75 | $0.48 | https://www.adafruit.com/product/2784
100 ohm resistor | 2 | $0.03 | 25 | $0.75 | $0.06 | https://www.adafruit.com/product/4293
DIP IC sockets | 3 | $0.09 | 122 | $10.84 | $0.27 | https://www.amazon.com/Glarks-122Pcs-Sockets-Adaptor-Assortment/dp/B01GOLSUAU
Thumb joystick | 2 | $3.95 | 1 | $3.95 | $7.90 | https://www.sparkfun.com/products/9032
Thumb breakout board | 2 | $1.95 | 1 | $1.95 | $3.90 | https://www.sparkfun.com/products/9110
TOTAL ASSEMBLY COST |  |  |  |  | $232.87

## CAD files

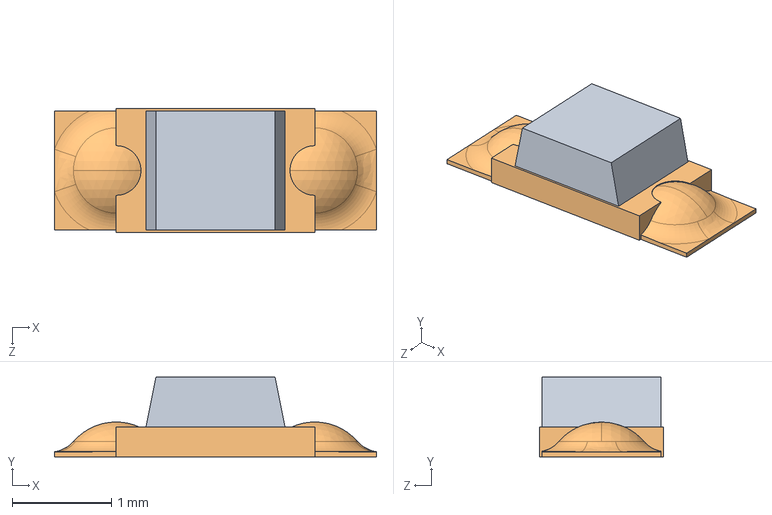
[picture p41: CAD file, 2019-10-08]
STEP AP203/MICRO_led2.step
3.24 x 0.8 x 1.25 mm

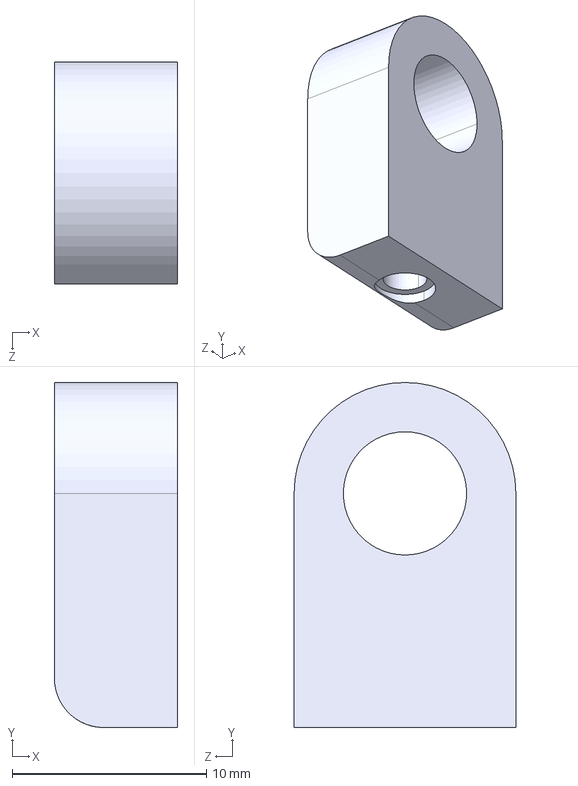
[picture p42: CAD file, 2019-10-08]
STEP AP214/G0006_shaft_guide.step
6.35 x 17.8 x 11.4 mm

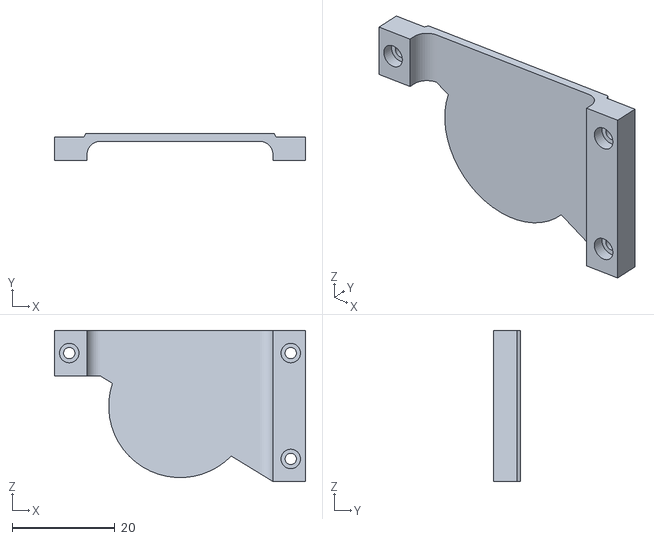
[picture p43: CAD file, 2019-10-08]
STLs/C002_right_speaker_brace.STL
48.9 x 5.24 x 29.4

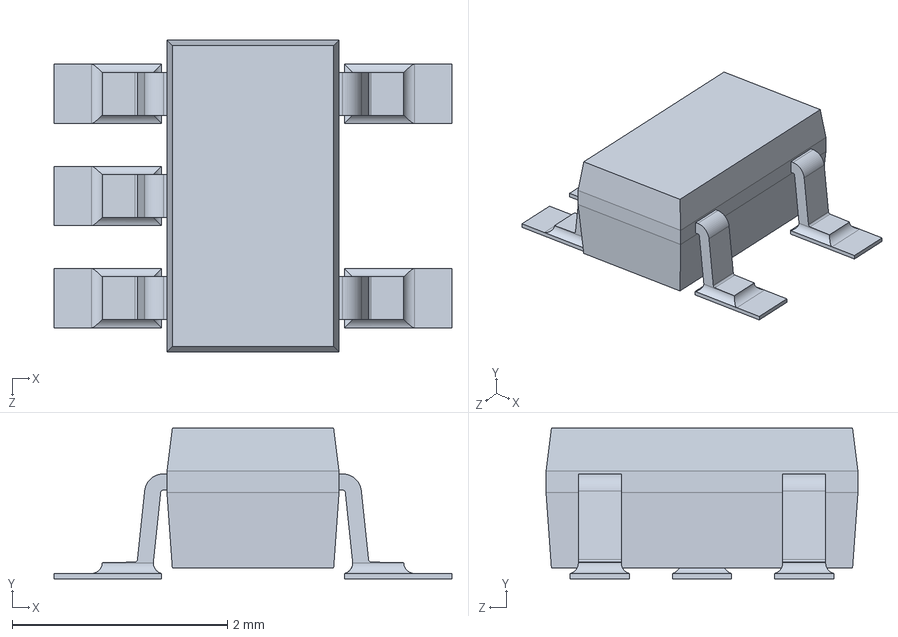
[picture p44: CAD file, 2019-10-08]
STEP AP203/micro_lmv358.step
3.70 x 1.40 x 2.90 mm

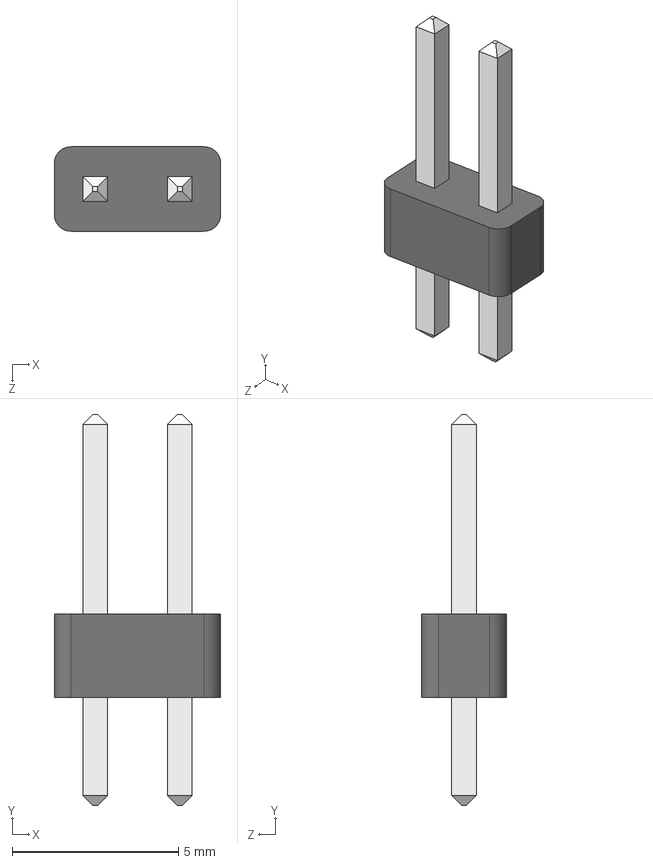
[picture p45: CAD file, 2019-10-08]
STEP AP214/MICRO_2pin_header__02.step
5.00 x 11.8 x 2.54 mm

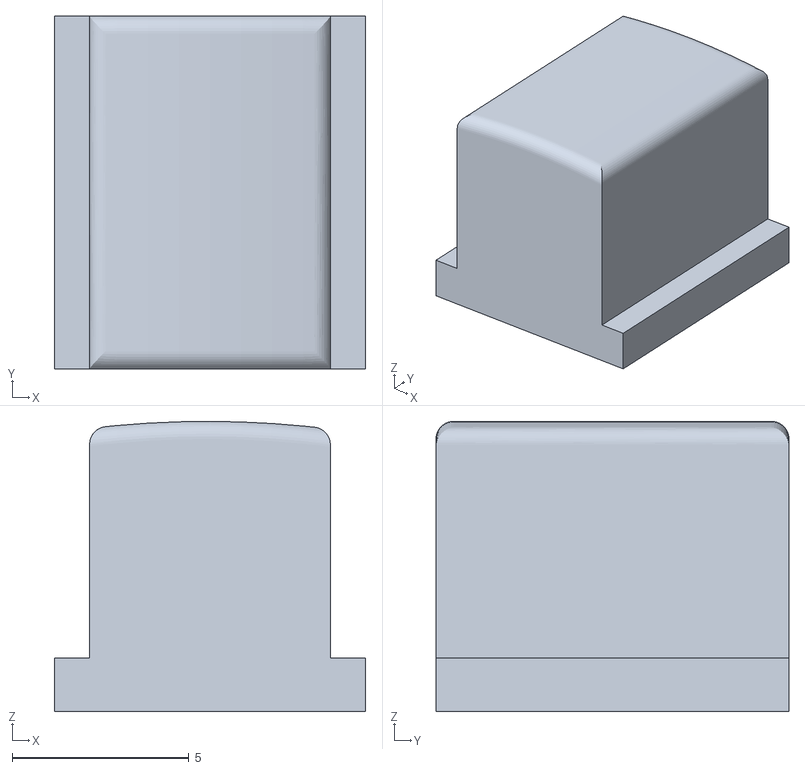
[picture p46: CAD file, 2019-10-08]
STLs/G0013_shoulderButton.STL
8.82 x 10.0 x 8.22

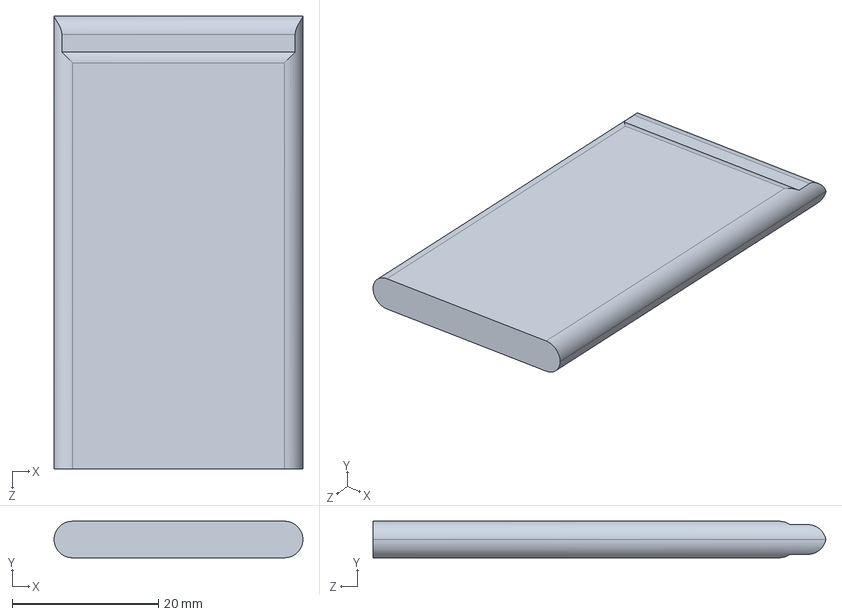
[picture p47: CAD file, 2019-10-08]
STEP AP203/dum_battery_1200.step
34.0 x 5.00 x 61.8 mm

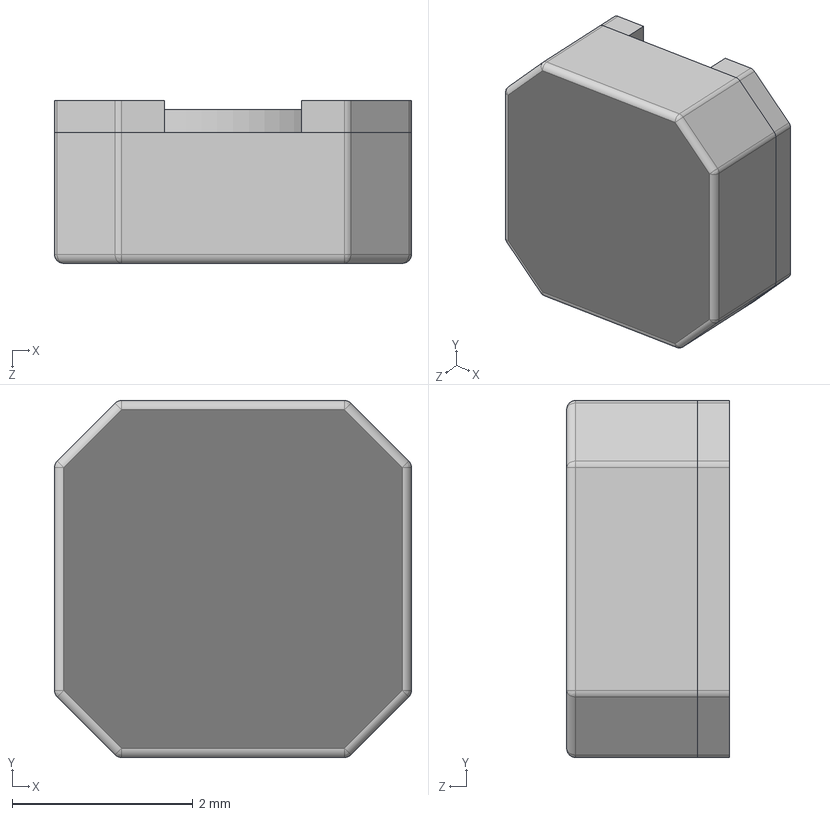
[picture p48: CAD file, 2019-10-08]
STEP AP214/LPS4018.step
3.95 x 3.95 x 1.80 mm

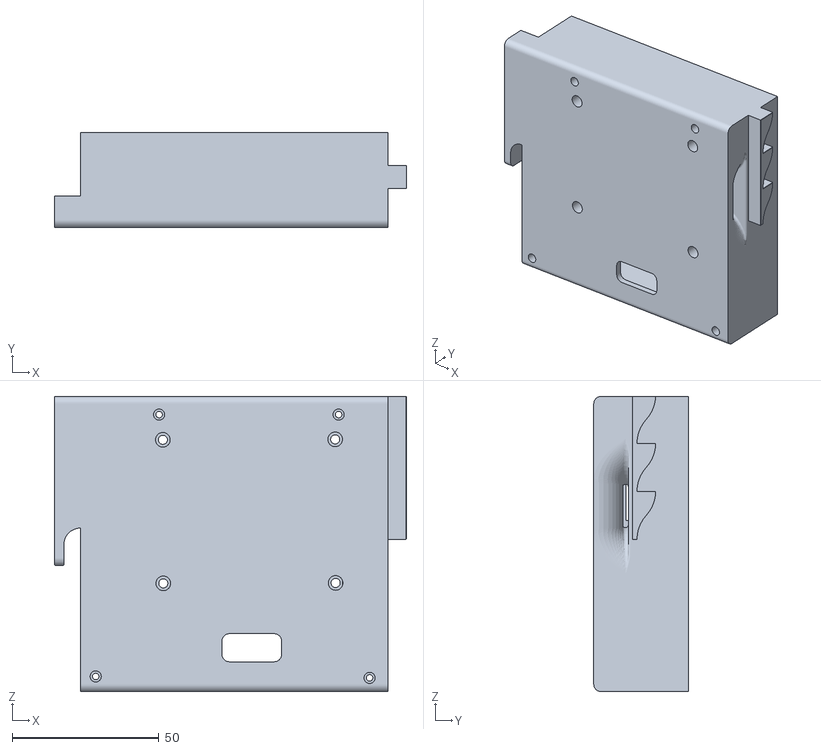
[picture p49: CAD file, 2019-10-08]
STLs/C000_bottom_case.STL
119.9 x 32.2 x 100.6

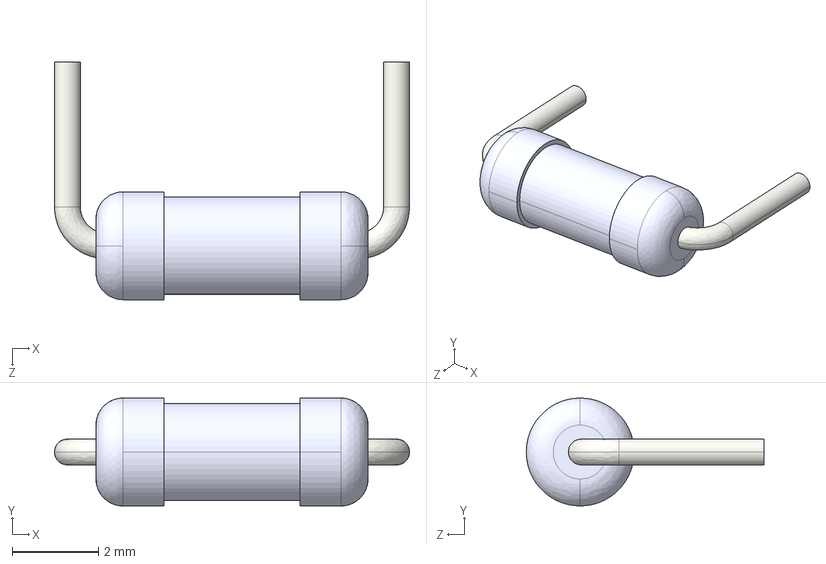
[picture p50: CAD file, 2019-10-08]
STEP AP214/R_Axial_DIN0207_L6_3mm_D2_5mm_P7_62mm_Horizontal004.step
8.22 x 2.50 x 5.50 mm

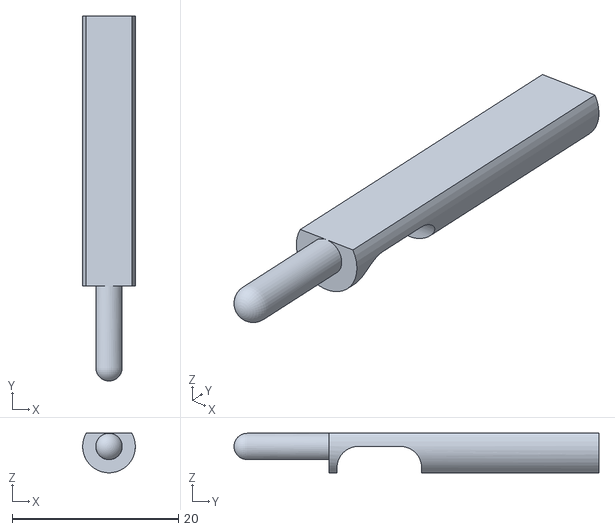
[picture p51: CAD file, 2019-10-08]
STLs/G0005_console_release_tip.STL
6.35 x 43.9 x 4.75

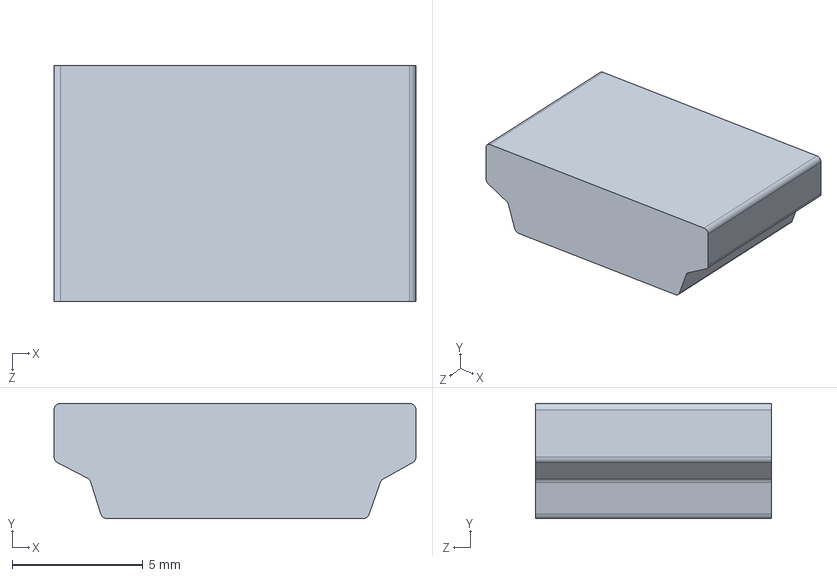
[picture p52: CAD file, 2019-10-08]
STEP AP203/dum_hdmi_male.step
13.8 x 4.41 x 9.00 mm

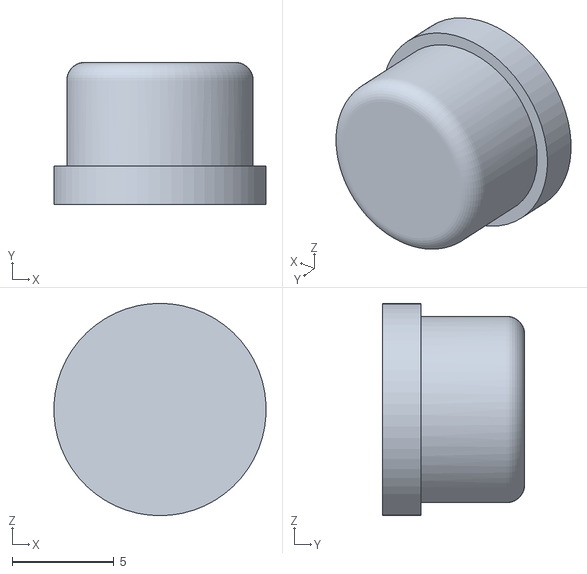
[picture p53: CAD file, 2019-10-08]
STLs/G0012_faceButton.STL
10.4 x 6.99 x 10.4

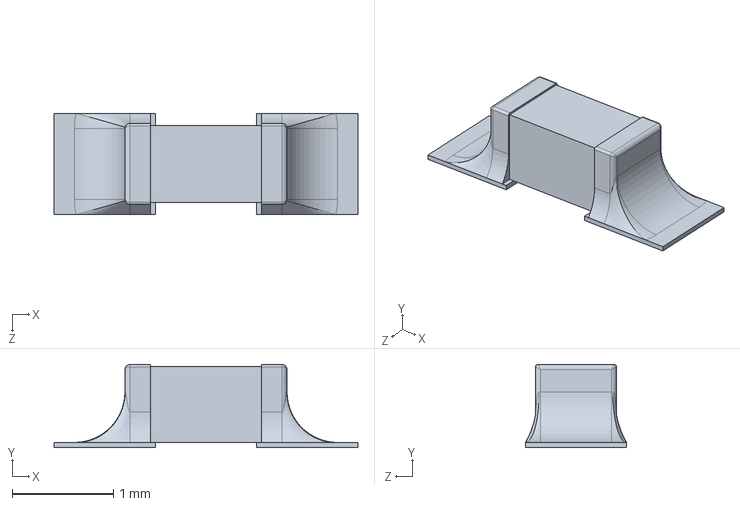
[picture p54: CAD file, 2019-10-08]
STEP AP203/CG0603MLC-05E.step
3.00 x 0.82 x 1.00 mm

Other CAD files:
STLs/G0011_catch_and_release_enclosure.STL
STEP AP203/dum_battery.step
STEP AP214/G0010_gamepad_left_top.step
STLs/G002_dual_shaft_cap.STL
STEP AP203/10029449-111RLF_hdmi_recepticale.step
STEP AP203/15mm_M2.5_standoff.step
STEP AP203/3.5_plug_terminal_block.step
STEP AP203/3.5mm Plug.step
STEP AP203/3.5mm_headphone_jack.step
STEP AP203/3.5mm_plug_housing.step
STEP AP203/6061K411_HARDENED PRECISION STEEL SHAFT.step
STEP AP203/6061K413_HARDENED PRECISION STEEL SHAFT.step
STEP AP203/9032.step
STEP AP203/90695A025_CLASS 04 STEEL THIN HEX NUT - DIN 439B.step
STEP AP203/91290A013_BLACK-OXIDE CLASS 12.9 SOCKET HEAD CAP SCREW.step
STEP AP203/92005A061_METRIC PAN HEAD PHILLIPS MACHINE SCREW.step
STEP AP203/9657K810_STEEL COMPRESSION SPRING.step
STEP AP203/C000_bottom_case.step
STEP AP203/C001_top_case.step
STEP AP203/C002_right_speaker_brace.step
STEP AP203/C003_left_speaker_brace.step
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

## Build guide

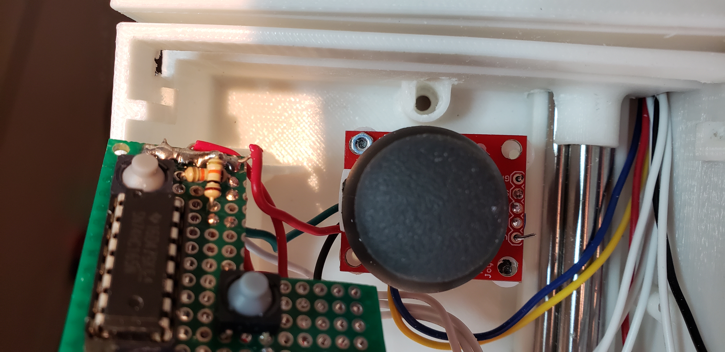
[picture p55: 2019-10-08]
images/partial_install_left_thumbstick.jpg

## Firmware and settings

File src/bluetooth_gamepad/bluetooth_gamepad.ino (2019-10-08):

/* THE CIRCUIT
   Push Button (x14)
   -5V to push button
   -10k resistor from GND to pushbutton
   -SN74HC165N data input to 10K resistor

   Thumb Joystick (x2)
   -VCC to 5V
   -VERT to arduino analog pin
   -HORZ to arduino analog pin
   -SEL to arduino digital pin, 10k resistor to arduino digital pin from GND
   -GND to ground

   Shift register 0 [directly connected to arduino]
   -parrallel load to arduino digital pin
   -clock input to arduino digital pin
   -GND to ground
   -serial output to arduino digital pin
   -serial input to serial output of shift register 2
   -clock enable to arduino digital pin
   -VCC to 5V

   Shift register 1 [connected to shift register 0]
   -parrallel load to parralel load of shift register 0
   -clock input to clock input of shift register 0
   -GND to ground
   -serial output to serial input of shift register 0
   -clock enable to clock enable of shift register 0
   -VCC to 5V

   Bluesmirf
   -RX-I pin connected to pin 0
   -TX-o pin connected to pin 1
   -GND to ground
   -VCC to 5V

*/

/*  NOTES AND METHODOLOGY
  "Serial1" is the hardware serial port of the arduino micro, used to communicate with the BlueSmirf
  "Serial", is the virtual serial port of the arduino micro

  The push buttons of the analog sticks are "active low" meaning when pushed their digital values is 0 while normally
  push buttons have a digital value of 1 when pushed. I've modified the read_shift_regs() function
  so the push buttons are active high

  Hardware serial is used to communicate to the bluesmirf.
  The software serial is used to print to the serial monitor and upload code

*/

//how many shift register chips are daisy-chained.
const int NUMBER_OF_SHIFT_CHIPS = 2;

//width of data (how many ext lines).
const int DATA_WIDTH = NUMBER_OF_SHIFT_CHIPS * 8;

//width of pulse to trigger the shift register to read and latch.
const int PULSE_WIDTH_USEC = 5;

//optional delay between shift register reads.
const int POLL_DELAY_MSEC = 5;

//You will need to change the "int" to "long" If the
#define INPUT_DATA_TYPE unsigned int

//Store what shift register pins are connected to the
//analog stick push buttons. This is done to ensure they are active
//low.
const int ANALOG_STICK_BUTTON_INPUTS[2] = {4, 12};

//define shift register pins
const int ploadPin        = 2;  // Connects to Parallel load pin the 165
const int clockEnablePin  = 3;  // Connects to Clock Enable pin the 165
const int dataPin         = 4; // Connects to the Q7 pin the 165
const int clockPin        = 5; // Connects to the Clock pin the 165

//define joystick pins
const int analogAxisPins[4] = {0, 1, 2, 3}; //represent X1,Y1,X2, and Y2 values

//intialize input values
INPUT_DATA_TYPE pinValues;
INPUT_DATA_TYPE oldPinValues;

signed int analogAxisValues[4] = {0, 0, 0, 0}; //represent X1,Y1,X2, and Y2 values
signed int oldAnalogAxisValues[4] = {0, 0, 0, 0}; //represent X1,Y1,X2, and Y2 values

//intialize output of bluesmirf
byte startByte = 0XFD;
byte lengthByte = 0x06;
byte leftControllerButtons  = 0;
byte rightControllerButtons = 0;

void setup()
{
  //CONFIGURE BLUESMIRF
  Serial1.begin(115200);  // set hardware serial to 115200 baud rate (bluesmirf default)

  //enter command mode
  Serial1.print("$$$");
  delay(100);// Short delay, wait for the Mate to send back CMD
  Serial1.flush();

  // Temporarily Change the baudrate to 9600, no parity
  Serial1.print("U,9600,N");
  Serial1.print("\r");
  Serial1.print("\n");
  Serial1.flush();

  // Start bluetooth serial at 9600
  Serial1.begin(9600);

  //CONFIGURE SHIFT REGISTERS
  Serial.begin(9600);
  Serial.println("Virtual serial is open.");

  /* Initialize our digital pins...
  */
  pinMode(ploadPin, OUTPUT);
  pinMode(clockEnablePin, OUTPUT);
  pinMode(clockPin, OUTPUT);
  pinMode(dataPin, INPUT);

  digitalWrite(clockPin, LOW);
  digitalWrite(ploadPin, HIGH);

  /* Read in and display the pin states at startup.
  */
  pinValues = read_shift_regs();
  display_pin_values();
  oldPinValues = pinValues;

}

void loop()
{
  //read button values
  pinValues = read_shift_regs();

  //read analog axis values
  for (int i = 0; i < 4; i++) {
    analogAxisValues[i] = map(analogRead(analogAxisPins[i]), 0, 1023, -127, 127);
  }

  //Split the button input into bytes that you'll send via bluetooth
  for (int i = 0; i < DATA_WIDTH; i++) {

    if (i <= 7)
    {
      bitWrite(leftControllerButtons, i, (pinValues >> i) & 1);
    }
    else
    {
      bitWrite(rightControllerButtons, i - 8, (pinValues >> i) & 1);
    }
  }

  sendHIDreport();

  /* If there was a chage in state, display which ones changed.
  */
  if (pinValues != oldPinValues /*|| analogAxisValues != oldAnalogAxisValues*/)
  {
    Serial.print("*Pin value change detected*\r\n");
    display_pin_values();
    Serial.print("Left Controller Byte: ");
    Serial.println(leftControllerButtons);
    Serial.print("Right Controller Byte: ");
    Serial.println(rightControllerButtons);

    oldPinValues = pinValues;
    for (int i = 0; i < 3; i++) {
      oldAnalogAxisValues[i] = analogAxisValues[i];
    }
  }

  //allow communication to the blueSMIRF via the serial monitor
  if (Serial1.available()) //If the bluetooth sent any characters
  {
    // Send any characters the bluetooth prints to the serial monitor
    Serial.print((char)Serial1.read());
  }
  else
  {
    //Clear the stream when there is not else to send
    Serial1.flush();
  }

  if (Serial.available()) // If stuff was typed in the serial monitor
  {
    // Send any characters the Serial monitor prints to the bluetooth
    Serial1.print((char)Serial.read());
  }
  else
  {
    //clear the stream when there is nothing else to print
    Serial1.flush();
  }

  delay(POLL_DELAY_MSEC);
}

/* This function is essentially a "shift-in" routine reading the
   serial Data from the shift register chips and representing
   the state of those pins in an unsigned integer (or long).
*/
INPUT_DATA_TYPE read_shift_regs()
{
  long bitVal;
  INPUT_DATA_TYPE bytesVal = 0;

  /* Trigger a parallel Load to latch the state of the data lines,
  */
  digitalWrite(clockEnablePin, HIGH);
  digitalWrite(ploadPin, LOW);
  delayMicroseconds(PULSE_WIDTH_USEC);
  digitalWrite(ploadPin, HIGH);
  digitalWrite(clockEnablePin, LOW);

  /* Loop to read each bit value from the serial out line
     of the SN74HC165N.
  */
  for (int i = 0; i < DATA_WIDTH; i++)
  {
    //make the analog stick buttons active high
    if (i == (ANALOG_STICK_BUTTON_INPUTS[0] - 1) || i == (ANALOG_STICK_BUTTON_INPUTS[1] - 1) ) {
      bitVal = not(digitalRead(dataPin));
    }
    else {
      bitVal = digitalRead(dataPin);
    }

    /* Set the corresponding bit in bytesVal.
    */
    bytesVal |= (bitVal << ((DATA_WIDTH - 1) - i));

    /* Pulse the Clock (rising edge shifts the next bit).
    */
    digitalWrite(clockPin, HIGH);
    delayMicroseconds(PULSE_WIDTH_USEC);
    digitalWrite(clockPin, LOW);
  }

  return (bytesVal);
}

/* Dump the list of zones along with their current status.
*/
void display_pin_values()
{
  Serial.print("Pin States:\r\n");

  for (int i = 0; i < DATA_WIDTH; i++)
  {
    Serial.print("  Pin-");
    Serial.print(i);
    Serial.print(": ");

    //if ((pinValues >> ((DATA_WIDTH - 1) - i)) & 1) {
    if ((pinValues >> i) & 1) {
      Serial.print("HIGH");
    }
    else {
      Serial.print("LOW");
    }

    Serial.print("\r\n");
  }
  Serial.print("PinValues equals: ");
  Serial.println(pinValues, BIN);
  Serial.print("X1: ");
  Serial.println(analogAxisValues[0]);
  Serial.print("Y1: ");
  Serial.println(analogAxisValues[1]);
  Serial.print("X2: ");
  Serial.println(analogAxisValues[2]);
  Serial.print("Y2: ");
  Serial.println(analogAxisValues[3]);

  Serial.print("\r\n");
}

/*
   Make and send the HID report that the bluetooth module will send
*/
void sendHIDreport()
{
  byte gamepad_buffer[8] = {0, 0, 0, 0, 0, 0, 0, 0};
  gamepad_buffer[0] = startByte;
  gamepad_buffer[1] = lengthByte;
  gamepad_buffer[2] = analogAxisValues[0]; //X1 axis
  gamepad_buffer[3] = analogAxisValues[1]; //Y1 axis
  gamepad_buffer[4] = analogAxisValues[2]; //X2 axis
  gamepad_buffer[5] = analogAxisValues[3]; //Y2 axis
  gamepad_buffer[6] = leftControllerButtons; //Buttons 0-7
  gamepad_buffer[7] = rightControllerButtons; //Buttons 8-15

  Serial1.write(gamepad_buffer, 8);
}

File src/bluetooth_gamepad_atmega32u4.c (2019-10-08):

/* Bluetooth Gamepad Firmware

The Circuit

   Push Button (x14)
   -5V to push button
   -10k resistor from GND to pushbutton
   -SN74HC165N data input to 10K resistor

   Thumb Joystick (x2)
   -VCC to 5V
   -VERT to arduino analog pin
   -HORZ to arduino analog pin
   -SEL to arduino digital pin, 10k resistor to arduino digital pin from GND
   -GND to ground

   Shift register 0 [directly connected to arduino]
   -parrallel load to arduino digital pin
   -clock input to arduino digital pin
   -GND to ground
   -serial output to arduino digital pin
   -serial input to serial output of shift register 2
   -clock enable to arduino digital pin
   -VCC to 5V

   Shift register 1 [connected to shift register 0]
   -parrallel load to parralel load of shift register 0
   -clock input to clock input of shift register 0
   -GND to ground
   -serial output to serial input of shift register 0
   -clock enable to clock enable of shift register 0
   -VCC to 5V

   Bluesmirf
   -RX-I pin connected to pin 0
   -TX-o pin connected to pin 1
   -GND to ground
   -VCC to 5V

NOTES AND METHODOLOGY

  The push buttons of the analog sticks are "active low" meaning when pushed their digital values is 0 while normally
  push buttons have a digital value of 1 when pushed. I've modified the read_shift_regs() function
  so the push buttons are active high

Shout out to the good people at SparkFun, Adafruit, Arduino and others I'm forgetting for being so helpful

*/

#define F_CPU 16000000
#define BAUD  115200
#define BRC   ((F_CPU/8/BAUD) - 1)

#include <avr/io.h>
#include <avr/interrupt.h>

#include <util/delay.h>
#include <util/setbaud.h>

#include <stdio.h>
#include <stdlib.h>
#include <stdbool.h>

/* How many shift register chips are daisy-chained.
*/
#define NUMBER_OF_SHIFT_CHIPS   2

/* Width of data (how many ext lines).
*/
#define DATA_WIDTH   NUMBER_OF_SHIFT_CHIPS * 8

/* Width of pulse to trigger the shift register to read and latch.
*/
#define PULSE_WIDTH_USEC   5

/* Optional delay between shift register reads.
*/
#define POLL_DELAY_MSEC   1

/* You will need to change the "int" to "long" If the
 * NUMBER_OF_SHIFT_CHIPS is higher than 2.
*/
#define BYTES_VAL_T unsigned int

/* Set up pins*/
const uint8_t ploadPin        = PD1;  // Connects to Parallel load pin of the shift register
const uint8_t clockEnablePin  = PD0;  // Connects to Clock Enable pin of the shift register
const uint8_t dataPin         = PD4; // Connects to the Q7 pin the of the shift register
const uint8_t clockPin        = PC6; // Connects to the Clock pin of the shift register

const uint8_t ANALOG_STICK_BUTTON_INPUTS[2] = {4,12};//these are the analog stick buttons that are active low

/*define joystick pins*/
const uint8_t axis1Pin   = PF7;//x1
const uint8_t axis2Pin   = PF6;//y1
const uint8_t axis3Pin   = PF5;//x2
const uint8_t axis4Pin   = PF4;//y2

/* set up variable values*/
BYTES_VAL_T pinValues;
signed char analogAxisValues[4] = {0, 0, 0, 0}; //represent X1,Y1,X2, and Y2 values
char leftControllerButtons  = 0;
char rightControllerButtons = 0;

/*intialize static bits of blueSMIRF*/
char startByte              = 0XFD;
char lengthByte             = 0x06;

/*prototype functions*/
BYTES_VAL_T read_shift_regs();
void USART_Init(uint32_t baud);
void USART_Transmit(signed char data);
void sendHIDreport();
signed char _map(long x, long in_min, long in_max, long out_min, long out_max);

uint8_t main(){
  /*intialize UART */
  USART_Init(BAUD);

  /*set pins as output*/
  DDRD = 0xFF;
  DDRB = 0XFF;
  DDRC = 0xFF;
  DDRE = 0xFF;
  DDRF = 0xFF;

  DDRD |= 1 << ploadPin;
  DDRD |= 1 << clockEnablePin;
  DDRD &= ~(1 << dataPin);
  DDRC |= 1 << clockPin;

  DDRF &= ~(1 << axis1Pin);
  DDRF &= ~(1 << axis2Pin);
  DDRF &= ~(1 << axis3Pin);
  DDRF &= ~(1 << axis4Pin);

  //intialize clockPin and ploadPin and pinValues
  PORTD &= ~(1 << clockEnablePin);
  PORTD |= 1 << ploadPin;

  pinValues = read_shift_regs();

  //loop forever
  while(1){
    /*read shift register and store the variables*/
    pinValues = read_shift_regs();

    /*read anlog axises*/
    ADMUX   = 0b01100000; // read from PC0
    ADCSRA  = 0b10000111; // Enable ADC and set the prescaler to max
    ADCSRA = ADCSRA | (1 << ADSC);
    while(ADCSRA & (1 << ADSC));// wait until the ADSC bit is clear
    analogAxisValues[0] = _map(ADCH, 0, 1023, -127, 127);

    ADMUX   = 0b01100001; // read from PC1
    ADCSRA  = 0b10000111;
    ADCSRA = ADCSRA | (1 << ADSC);
    while(ADCSRA & (1 << ADSC));
    analogAxisValues[1] = _map(ADCH, 0, 1023, -127, 127);

    ADMUX   = 0b01100010; // read from PC2
    ADCSRA  = 0b10000111;
    ADCSRA = ADCSRA | (1 << ADSC);
    while(ADCSRA & (1 << ADSC));
    analogAxisValues[2] = _map(ADCH, 0, 1023, -127, 127);

    ADMUX   = 0b01100011; // read from PC3
    ADCSRA  = 0b10000111;
    ADCSRA = ADCSRA | (1 << ADSC);
    while(ADCSRA & (1 << ADSC));
    analogAxisValues[3] = _map(ADCH, 0, 1023, -127, 127);

    /*split the button input into bytes that will be sent via bluetooth*/
    for (int i = 0; i < DATA_WIDTH; i++){
      if (i <= 7){
        if ((pinValues >> i) & 1){
          leftControllerButtons |= 1 << i;
        } else {
          leftControllerButtons &= ~(1 << i);
        }

      } else {
        if ((pinValues >> i) & 1){
          rightControllerButtons |= 1 << i;
        } else {
          rightControllerButtons &= ~(1 << i);
        }
      }
    }

    sendHIDreport();

    _delay_ms(POLL_DELAY_MSEC);
  }
  return 0;
}

/* This function is essentially a "shift-in" routine reading the
 * serial Data from the shift register chips and representing
 * the state of those pins in an unsigned integer (or long).
*/
BYTES_VAL_T read_shift_regs(){
  long bitVal;
  BYTES_VAL_T bytesVal = 0;

  PORTD |= 1 << clockEnablePin;
  PORTD &= ~(1<<ploadPin);
  _delay_us(PULSE_WIDTH_USEC);
  PORTD |= 1 << ploadPin;
  PORTD &= ~(1<<clockEnablePin);

  /* Loop to read each bit value from the serial out line of the SN74HC165N.*/
  for(int i = 0; i < DATA_WIDTH; i++){
    bitVal   = PIND & (1 << dataPin);

    /* Set the corresponding bit in bytesVal.*/
    bytesVal |= (bitVal << ((DATA_WIDTH-1) - i));

    /* Pulse the Clock (rising edge shifts the next bit).*/
    PORTC |= 1 << clockPin;
    _delay_us(PULSE_WIDTH_USEC);
    PORTC &= ~(1<<clockPin);
  }
  return bytesVal;
}

/*Intialize UART*/
void USART_Init(uint32_t baud){
  /* Set baud rate */
  UBRR1H = (unsigned char)(baud>>8);
  UBRR1L = (unsigned char) baud;

  /* Enable receiver and transmitter */
  UCSR1B = (1<<RXEN1)|(1<<TXEN1);

  /* Set frame format: 8data, 2stop bit */
  UCSR1C = (1<<USBS1)|(3<<UCSZ10);
}


//Transmit a single bit over UART
void USART_Transmit(signed char data){
  while(!UCSR1A & (1<<UDRE1));
  UDR1 = data;
}
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
